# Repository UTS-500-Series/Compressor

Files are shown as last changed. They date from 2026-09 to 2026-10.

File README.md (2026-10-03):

# UTS Mini Mixing Desk — Compressor

A 500-series compressor module for the UTS Mini Mixing Desk. Feedback topology, discrete
current-steering gain cell, balanced in and out, running on the rack's ±16 V.

Built from ordinary parts: **nine BC549 transistors and seven NE5532 op amps**, plus a
pair of LM391x bargraph drivers for the meters. No VCA chip,
no transformers, nothing hard to source.

📖 **Documentation: [uts-500-series.github.io/compressor](https://uts-500-series.github.io/compressor/)** — every section explained, with
interactive schematics you can click through, plus the routed boards and their design files.
The site's source is a separate repository, [UTS-500-Series.github.io](https://github.com/UTS-500-Series/UTS-500-Series.github.io).

---

## Status

| | |
|---|---|
| Schematic | Complete, 7 sheets |
| Components | 166 |
| Nets | 110 |
| ERC | 0 errors, 0 warnings |
| PCB layout | Main board and front board placed and routed, DRC clean. Main board re-routed with paired audio lines and an unbroken ground pour; front board still as autorouted |
| Simulated | Yes, in ngspice from the `kicad/` sheets. See [kicad/sim](kicad/sim/README.md) |
| Built | No |

**Every performance figure in the documentation is calculated from the design, not measured.**
The netlist has been verified and ERC is clean, but that only proves the drawing is
self-consistent — not that the circuit behaves as predicted. The [simulation](kicad/sim/README.md)
checks the behaviour with models of the real parts, and found a few places where it differs
from the documentation.

## Repository layout

```
kicad_withpcb/compressor_with_pcb/   the main board: flat schematic + routed PCB (KiCad 10)
kicad_withpcb/compressor_front/      the front board behind the panel: schematic + routed PCB
kicad/                               the original seven-sheet schematic (KiCad 9), used by the site
tools/                               design.py (the reference netlist) and the check/build scripts
panel/                               faceplate generator — mockups, a 1:1 drawing and a DXF
```

**The boards are built from `kicad_withpcb/`.** The flat schematic there drives the main
board's PCB, and the front board has its own schematic joined to it by a 30-way ribbon.
`tools/design.py` is the reference netlist. Compare the flat schematic against it after any
wiring edit: KiCad's DRC parity check only compares the PCB with the flat schematic, so it
can't see a wiring mistake in the schematic itself.

The seven-sheet `kicad/` project is the original drawing of the same circuit. It has no PCB,
but the documentation site's interactive schematics are built from it. The site lives in its
own repository, [UTS-500-Series.github.io](https://github.com/UTS-500-Series/UTS-500-Series.github.io),
because it covers the whole desk rather than this module.

## Opening it

The boards need **KiCad 10**:

- `kicad_withpcb/compressor_with_pcb/compressor_with_pcb.kicad_pro`: the main board, the
  500-series card (152.35 × 105 mm) with the edge connector.
- `kicad_withpcb/compressor_front/compressor_front.kicad_pro`: the 35 × 110 mm front board
  with the pots, toggles and meters. Its [README](kicad_withpcb/compressor_front/README.md)
  covers how it mounts, the ribbon, the bracket and what to check before ordering.

Run `sh tools/get_3d_models.sh` once after cloning. It fetches Alps' RK09K pot model, which
isn't kept in git, so the 3D viewer and STEP export show the pots.

The original schematic is `kicad/UTS Mini Mixing Desk - Compressor.kicad_pro` (**KiCad 9**). Its root sheet holds seven
sub-sheets:

| Sheet | What it covers |
|---|---|
| 1 Connector | The 500-series edge connector |
| 2 Input | Balanced receiver and the input pad |
| 3 VCA | The current-steering gain cell and recovery amplifier |
| 4 Output | Makeup gain, output drivers, bypass, aux section |
| 5 Sidechain | Detector: threshold, rectifier, ratio, attack/release |
| 6 Power | Rails, references, bias, grounding, decoupling |
| 7 Meters | Gain-reduction and output-level LED bargraphs |

Only stock KiCad symbol and footprint libraries are used, so there is nothing to install.

## How it works, in one paragraph

A compressor needs a gain it can change electrically, and a way to measure loudness. The gain
cell here keeps a **fixed 3 mA tail current** through a matched BC549 pair and varies gain by
*steering* that current between an output load and the supply rail, rather than by varying the
current itself. That costs four extra transistors and buys a distortion figure that stays flat
at every amount of gain reduction — the simpler tail-current approach distorts worst exactly
when it is compressing hardest. The detector listens to the module's own **output**, making
this a feedback compressor: the ratio emerges from loop gain rather than being dialled in, the
knee comes out soft on its own, and the circuit is forgiving of component tolerance.

The [documentation](../UTS-500-Series.github.io) covers all of this properly, section by section.

## Specifications

| | |
|---|---|
| Format | 500 series, 15-pin EDAC card edge |
| Supply | ±16 V from the rack, 72 / 62 mA at rest (simulated) |
| Input | Balanced, 44 kΩ differential, +4 dBu nominal |
| Output | Balanced, 100 Ω build-out per leg |
| Gain reduction | 36 dB maximum (simulated) |
| Attack | 2 – 71 ms (simulated) |
| Release | 49 ms – 3.5 s (simulated) |
| Controls | Threshold, Ratio, Attack, Release, Makeup |
| Switches | Bypass, sidechain key int/ext, sidechain HPF, stereo link |

## Front panel

[`panel/`](panel/) holds the faceplate: a mockup, a dimensioned 1:1 drawing, and a DXF of the
outline and holes for a panel shop. All three are generated from one definition by
`panel/make_panel.py`, which runs a clearance check on every build.

Panel is the standard 500-series 1.500″ × 5.250″ × 0.125″ with two countersunk mounting holes
125.43 mm apart, badged **OPN-500 / CMP-01**.

The default layout, and the one the front board is built for, is **`toggle`**: five single
9 mm pots (THRESHOLD, RATIO, ATTACK, RELEASE, MAKEUP), four mini toggles (HPF and KEY
either side of THRESHOLD, LINK and BYPASS either side of RATIO), and two 10-LED meters for
gain reduction and output level. That's 31 holes, and `make_panel.py` takes their
positions from the front board. The toggles are Salecom mini toggles from Altronics:
S1350 (DPDT) for BYPASS and S1315 (SPDT) for KEY, HPF and LINK, in 6.5 mm holes for their
1/4-40 bushings. The S1332 (SPDT centre-off) fits the same footprint if a three-position
switch is ever wanted.

The toggles' 8.9 mm bushing leaves about 5.5 mm of thread through a 3.18 mm panel, so they
are no longer the tight spot. The 9 mm pots are: their 5 mm bushing leaves under 2 mm for
the nut, so thin the panel to about 2 mm around the five pot holes, or use a thinner panel.

`make_panel.py` also keeps a `pull` layout (every switch on a pull-switch pot) and a
`concentric` layout (dual-concentric knobs and a lit BYPASS button), plus a `bone` finish
alongside the default dark anodised one. The boards are only drawn for `toggle`. See
[`panel/README.md`](panel/README.md).

No laser cutter or CNC? [`panel/print/`](panel/print/README.md) has a 3D-printable faceplate
(STL and OpenSCAD) with the same holes, pot wells for the short pot bushings, an engraved
legend that can print in a second colour, and a fit-test strip to print first.

## Bill of materials

**[`bom/altronics.csv`](bom/altronics.csv)** is the order list for both boards from Altronics,
with catalogue codes, pack sizes, prices and the stock their site showed on the day it was
checked. `python3 tools/bom_altronics.py` rebuilds it from the two `kicad_withpcb`
schematics, so it follows the boards rather than `design.py`; a part drawn on both sheets
is counted once, on the front board. It includes the hardware the schematics don't: DIP-8
sockets for U1–U7, knobs, the board-to-board ribbon and M3 screws for the bracket. The
two LM3914 meter drivers are soldered straight in, because sockets would overlap the
meter LEDs.

Altronics doesn't stock everything. The script lists those lines with another supplier:
the 2.2–10 µF film capacitors, R61/R62 at 0.1%, and the twenty 2 mm meter LEDs (Altronics'
3 mm flangeless LEDs don't fit the meters' 3.0 mm pitch). The film capacitors come from element14, and
the main board is drawn for those exact parts: TDK B32562H1106K000 (10 µF, C5, C8, C15) and
B32562H1475K000 (4.7 µF, C9, C10), both 15 mm pitch, and KEMET MMK5225K63J06L4BULK
(2.2 µF, C14, C35) on 5 mm. RV5 (ATTACK) is 10k and RV6 (RELEASE) 1M, Altronics' nearest
9 mm values.

The output-level meter was an LM3915, whose ten steps are 3 dB apart. Nobody stocks it any
more, so U10 is now an LM3914 like the gain-reduction meter, and both meters have ten LEDs on
a 3.0 mm pitch (they had seven on 3.5 mm). R92 is 4k7, so RV8 can set the top level LED at
+18 dBu. The LM3914's steps are even in volts, so the level LEDs light at about −2, +4, +7.5,
+10, +12, +13.6, +15, +16, +17 and +18 dBu: a 20 dB span with the finest steps near
clipping. With RV7 set for a 30 dB top LED, the gain-reduction LEDs light at about 2, 3, 5,
7, 10, 13, 17, 21, 26 and 30 dB. Both scales are simulated: see
[kicad/sim/README.md](kicad/sim/README.md#the-meters).
`tools/bom_order.py` is the older DigiKey list, built from `design.py`.

The circuit itself is 172 components across 58 distinct line items: 73 resistors, 39 capacitors, 21 LEDs,
9 transistors, 8 potentiometers, 8 diodes, 7 op amps, 4 switches, 2 display drivers,
1 connector.

Four things are not substitutable:

- **Q1/Q2 must be a matched pair, and Q6–Q9 a matched quad**, all glued together so they stay
  at the same temperature. The steering balance is set by base-emitter voltages differing by
  tens of millivolts, and those drift ~2 mV per °C.
- **R1–R4 and R21–R24 want 0.1%.** R1–R4 set input common-mode rejection; R21–R24 set how well
  the recovery amp rejects the gain cell's step, which is audible as thump on fast attacks.
- **R61 (1k33) and R62 (23k2) want 0.1%.** They set the gain cell's resting point.
- **C15 must be film.** An electrolytic's leakage is in the same league as the release current
  at long settings and will shorten your slowest release.

One recommended deviation: fit a **TL072 or OPA2134 for U4** instead of an NE5532. Its inputs
sit on the timing capacitor, and the NE5532's ~200 nA bias current can leave the compressor
holding about a decibel of gain reduction at idle. Pin compatible, nothing else changes.

## Ordering the boards

Each board's fab files are in its `Gerbs/` folder, zipped ready to upload:
`kicad_withpcb/compressor_with_pcb/Gerbs/compressor_with_pcb-gerbers.zip` (main board,
128.4 × 105.05 mm including the edge-connector tab) and
`kicad_withpcb/compressor_front/Gerbs/compressor_front-gerbers.zip` (front board, 35 × 110 mm).
Both are 2-layer, 1.6 mm FR-4, 1 oz copper, through-hole only (no paste layers). Smallest
track 0.2 mm, clearance 0.2 mm, drill 0.4 mm, so any standard fab process takes them.

The main board's edge fingers plug into the rack, so ask for gold fingers with a 30–45° bevel
if the fab offers it. Plain HASL works for a prototype but wears with repeated insertion.

**Re-plot after every board change**, so the zips never lag the board:

```bash
sh tools/plot_fab.sh                 # both boards, needs KiCad 10's kicad-cli
```

## Documentation site

The site is a **separate repository**, checked out beside this one as `../UTS-500-Series.github.io`. It covers
every module in the desk — compressor, preamp and equaliser — so it does not belong to any
one of them. It also owns its own GitHub Pages workflow.

The compressor's pages are interactive: pan and zoom the real schematic, click any part for
its value, footprint and nets, click a net to highlight everything on it, or switch to a
graph view of the netlist.

The site commits its generated data, so it builds and publishes without this repository
present. It only needs this one checked out when the schematic changes — see below.

## Tooling

Everything needed to check and rebuild the project lives in [`tools/`](tools/) — standard
library only, no packages to install. KiCad's paths are found automatically; override with
`KICAD_CLI` and `KICAD_SYMBOL_DIR` if yours are somewhere unusual.

```bash
python3 tools/verify_netlist.py      # check the schematic against design.py
sh tools/plot_fab.sh                 # plot Gerbers + drill files for both boards
```

`tools/gen_project.py` and `tools/route_sch.py` **regenerate the schematic from scratch and
will overwrite hand-drawn layout.** They built the first version; the sheets have been laid out
by hand since. See [`tools/README.md`](tools/README.md) before running either.

## How the schematic is verified

`tools/design.py` holds the netlist as data and is treated as the source of truth.
`tools/verify_netlist.py` exports the netlist from the schematic with `kicad-cli` and diffs it
against that definition **net by net and pin by pin**.

That is what catches the failure mode ERC cannot see: a wire dragged so its endpoint lands on a
neighbouring node shorts two signal nets together, and ERC reports nothing, because every pin
is still connected to *something*. Two such shorts were caught and fixed this way during layout
cleanup. Worth running after any significant edit — it takes a second and prints the exact nets
and pins involved when something is wrong.

## Regenerating the documentation

After changing a sheet, from the **docs** repository beside this one:

```bash
# 1. re-export the sheet images
kicad-cli sch export svg --no-background-color --exclude-drawing-sheet -o /tmp/svg \
  "kicad/UTS Mini Mixing Desk - Compressor.kicad_sch"
#    copy the seven sheets into ../UTS-500-Series.github.io/site/compressor/img/ as connector.svg, input.svg,
#    vca.svg, output.svg, sidechain.svg, power.svg, meters.svg

cd ../UTS-500-Series.github.io
python3 build/_data.py --module compressor   # hotspots + netlist graph, read from kicad/
python3 build/build_site.py                  # every page, every module
```

Both scripts import from `tools/`, so a fresh clone has everything it needs.

## Known gaps

- **The main board was re-routed by script, not by hand, so look it over in KiCad before
  ordering.** IN± and OUT± now run as pairs 0.6 mm apart on the top layer, with one via each
  on IN− and OUT− beside the edge fingers. Nearly everything else moved to the top so the AGND
  pour on the bottom is one piece (it was seven, one of them cut off near the fingers). The cost
  is more vias: 155, up from 37. The timing node (C15, U4, D7, J2) is 44 mm, about as short as
  the placement allows; shortening it further means moving C15.
- **The front board's tracks are still as the autorouter left them**, with its ground pour in
  12 pieces. It carries the bypass switch's IN± and OUT± runs, so tidy those if anything.
- **Check one toggle and one pot against their footprints before ordering boards.** The
  Salecom footprints follow the drawings on Altronics' product pages; Altronics doesn't
  dimension where the 9 mm pot's shaft sits relative to its lugs, so confirm it lines up
  with the panel hole.
- **Check the mechanics in a real rack:** the front board now sits about 10.6 mm behind the
  panel (the pots' body height; the toggles stand 10.4 mm), the panel thickness at the pots,
  the ribbon length (about 150 mm is an estimate), and that the ribbon plug on J1 still
  clears the main board's front edge, 24 mm back.
- **The main board was re-placed and re-routed by script to fit the full-size film
  capacitors.** The film caps went in near their old spots, 56 resistors, small caps and
  diodes moved or swapped places to make room (transistors, ICs, connectors and trimmers
  stayed put), and the whole board was re-routed by script (see the item above). Keep the
  timing node (C15, U4) and the recovery-amp inputs (C9, C10, R21, R22, U1) short if you
  move anything.
- Pin 11 is used as an auxiliary input, which the API 500 specification assigns to a gain-trim
  node. The aux section (U5 and its resistors) is a separable block; omit it and the module is
  fully standards-compliant.
- Simulated in ngspice only (see [kicad/sim](kicad/sim/README.md)): no instability at the
  fastest attack and hardest ratio there, but the op amp model is behavioural, so check on the bench.

## Licence

Copyright 2026 the UTS 500 Series team.

This source describes Open Hardware and is licensed under the CERN-OHL-S v2.

You may redistribute and modify this source and make products using it under
the terms of the [CERN-OHL-S v2](https://ohwr.org/cern_ohl_s_v2.txt).

This source is distributed WITHOUT ANY EXPRESS OR IMPLIED WARRANTY, INCLUDING
OF MERCHANTABILITY, SATISFACTORY QUALITY AND FITNESS FOR A PARTICULAR PURPOSE.
Please see the CERN-OHL-S v2 for applicable conditions.

Source location: https://github.com/UTS-500-Series/Compressor

As per CERN-OHL-S v2 section 4, should You produce hardware based on this
source, You must where practicable maintain the Source Location visible on the
external case of the compressor module or other products you make
using this source.

The full licence text is in [LICENSE](LICENSE).

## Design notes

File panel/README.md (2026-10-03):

# Front panel — OPN-500 / CMP-01

Faceplate mockup and machining data for the compressor module.

Faceplate

| File | What it is |
|---|---|
| `faceplate-mockup.svg` | How it looks — whichever finish you built last. |
| `faceplate-mockup-bone.svg` | The other finish, written every run so you can compare. |
| `faceplate-drawing.svg` | 1:1 technical drawing, dimensioned, for checking before you cut. |
| `faceplate.dxf` | Outline and holes only, for a panel shop or CNC. |
| `make_panel.py` | Generates all of it from one definition. |
| [`print/`](print/README.md) | A 3D-printable version: STLs, the OpenSCAD model and print settings. |

Everything comes out of `make_panel.py`, so the picture and the machining data cannot drift
apart. Change a control position once and re-run:

```bash
python3 make_panel.py                          # toggle layout, anodised (default)
python3 make_panel.py --layout pull            # five knobs, every switch a pull
python3 make_panel.py --layout concentric      # concentric knobs, button, toggles
python3 make_panel.py --style bone             # light flat-graphic finish
python3 make_panel.py --layout toggle --style bone
```

## Layouts

The layout changes **what hardware is on the panel**, so the hole pattern, the drawing and the
DXF all change with it.

**`pull`** — five separate knobs. Every switch function is a pull on a pot, so
there are no toggles and no button at all: THRESHOLD pulls for the sidechain HPF, RATIO for
key int/ext, MAKEUP for bypass. LINK is an internal jumper. **27 holes.** The simplest panel
to build and the cheapest to populate, at the cost of a slow, uncertain bypass action.

*A note on the shared row:* ATTACK and RELEASE sit side by side on every layout, so they get a
smaller legend and no printed numerals — two full scales would print their endpoints on top of
each other in the gap between the knobs.

**`toggle`** *(default, and the one the front board is built for)* — the same five knobs, but every switch gets its own toggle rather than hiding on
a pull. They flank the two knobs they belong to: HPF and KEY either side of THRESHOLD, LINK and
BYPASS either side of RATIO. **31 holes.** Four more holes and four more parts than `pull`, and
in exchange every function is one positive movement — nothing is hidden, and bypass is instant.
The most parts of the three layouts, and the easiest to use.

**`concentric`** — two dual-concentric knobs (THRESHOLD/RATIO, ATTACK/RELEASE) free the space
for a latching illuminated BYPASS button and HPF / KEY toggles; LINK moves to the pull on
MAKEUP. **28 holes.** Better ergonomics, but concentric pots are dearer, harder to source, and
their inner shafts cannot carry a printed scale.

## Finishes

**`anodised`** *(default)* — dark panel, knurled knobs, teal accents. Reads as studio hardware.
The recessed meter window and the DYNAMICS / OUTPUT section rules appear on the concentric
layout only; the pull layout is plainer because it has no room for them.

**`bone`** — light panel, flat graphic treatment, printed dot scales with 0–10 numerals, thin
metal bat toggles, sage and terracotta. Closer to a plugin UI than a rack unit.

Every run writes the chosen combination as `faceplate-mockup.svg` and the other finish as
`faceplate-mockup-<name>.svg`, so comparing costs nothing.

## Panel dimensions

From the API 500 mechanical specification, not guessed:

| | Imperial | Metric |
|---|---|---|
| Width | 1.500″ | 38.10 mm |
| Height | 5.250″ | 133.35 mm |
| Thickness | 0.125″ | 3.18 mm |
| Mounting hole pitch | 4.938″ | 125.43 mm |
| Mounting hole Ø | 0.125″ | 3.18 mm |
| Countersink | 82° to 0.225″ | 82° to 5.72 mm |

Both mounting holes sit on the vertical centreline at x = 19.05 mm, which puts them
3.96 mm from each end.

## Drill schedule

For the `toggle` layout, which is what the front board (`kicad_withpcb/compressor_front`)
carries. That board is the master: these positions are copied from it, so change the board
first and then the numbers in `make_panel.py`.

Origin is the **top-left corner** of the panel, x right, y down. All in millimetres.

| Ref | Function | X (mm) | Y (mm) | Hole Ø | Hardware |
|---|---|---|---|---|---|
| `RV3` | THRESHOLD | 19.05 | 52.00 | 7.2 | 9 mm pot (Altronics R19xx or Alps RK09K), M7 bushing |
| `RV4` | RATIO | 19.05 | 72.50 | 7.2 | 9 mm pot |
| `RV5` | ATTACK | 10.00 | 91.00 | 7.2 | 9 mm pot |
| `RV6` | RELEASE | 25.10 | 91.00 | 7.2 | 9 mm pot |
| `RV2` | MAKEUP | 19.05 | 111.00 | 7.2 | 9 mm pot |
| `SW3` | HPF | 7.15 | 52.00 | 6.5 | mini toggle, SPDT, 1/4-40 bushing (Salecom S1315) |
| `SW2` | KEY | 30.95 | 52.00 | 6.5 | mini toggle, SPDT (Salecom S1315) |
| `SW4` | LINK | 7.15 | 72.50 | 6.5 | mini toggle, SPDT (Salecom S1315) |
| `SW1` | BYPASS | 30.95 | 72.50 | 6.5 | mini toggle, DPDT (Salecom S1350) |
| `D20`–`D29` | GR meter, 10 seg (D20 at the top) | 14.10 | 14.0 to 41.0, 3.0 pitch | 2.2 | 2 mm flat-top LED |
| `D30`–`D39` | LVL meter, 10 seg (D39 at the top) | 24.00 | 14.0 to 41.0, 3.0 pitch | 2.2 | 2 mm flat-top LED |
| — | mounting | 19.05 | 3.96 | 3.18 | c'sink 82° to Ø5.72 |
| — | mounting | 19.05 | 129.39 | 3.18 | c'sink 82° to Ø5.72 |

The front board sits about 10.6 mm behind the panel, set by the 9 mm pots' body height
(the toggles stand 10.4 mm). The toggles' 8.9 mm bushing leaves about 5.5 mm of thread in
front of a 3.18 mm panel, plenty for the washer and nut. The pots' 5 mm bushing leaves
under 2 mm, so thin the panel to about 2 mm around the five pot holes (a counterbore from
the back), or use a 1.6 to 2 mm panel. The toggles come with a tabbed locking washer; drill
a small hole for its tab if you want it, or flatten the tab.

The toggles sit 0.25 mm in from where the old sub-miniature ones were, so the S1350's
11.4 mm body stays on the 35 mm front board. In the `toggle` layout `make_panel.py` also
checks the switch and pot bodies behind the panel: each stays on the front board and at
least 0.5 mm from its neighbours. The tightest pair is BYPASS and RATIO, 1.3 mm apart.

ATTACK and RELEASE sit 1.5 mm left of symmetric so the ribbon header on the back of the
front board clears the RELEASE pot. The meter columns are 9.9 mm apart rather than 10.9 so
the two LM3914 meter drivers fit either side of them.

## Layout notes

**Dual-concentric knobs carry the four paired controls.** THRESHOLD over RATIO, ATTACK over
RELEASE — the outer ring is dark and knurled, the inner cap amber, so which one you have hold
of is obvious. This is what buys the room for two meters, a button and two toggles on a
38 mm panel; four separate knobs would eat 40 mm of height on their own.

The trade is cost and sourcing: dual-concentric pots are dearer and harder to find than two
singles, and you generally **cannot get a pull switch on one**, which is why the switch
functions live elsewhere.

**Control map**

| Position | Outer / primary | Inner / secondary |
|---|---|---|
| Upper concentric | THRESHOLD | RATIO |
| Lower concentric | ATTACK | RELEASE |
| Single knob | MAKEUP | pull for LINK |
| Button | BYPASS (latching, lit) | — |
| Toggles | HPF, KEY | — |

**`BYPASS` is a latching pushbutton** legended on its own face. The bottom screw owns the
centreline down there and there is no room for a legend beside it; putting the word on the cap
is what a real panel does anyway. It is illuminated, so bypass state is visible across a room.

**`LINK` is a pull on MAKEUP.** It is set once per stereo pair and then left, which makes it
the right function to hide behind a pull rather than give a switch to.

**Two 10-segment meters.** `GR` fills downward from the top as the compressor clamps; `LVL`
fills upward, green through amber to red. Twenty 2 mm LEDs on a 3.0 mm pitch, in a recessed
window, driven by two LM3914s in dot mode (one LED lit at a time; the mockups show a bar to
make the scale readable). The 3.0 mm pitch leaves 0.8 mm of metal between the 2.2 mm holes,
which `make_panel.py` allows for the meter holes only; everything else keeps 1.0 mm.

**On keeping every round.** The panel went through several iterations and only the most recent
reached git, so two earlier versions had to be rebuilt from scratch to get them back. Hence
`--layout` and `--style`: four combinations now regenerate from one definition and none can be
lost by choosing another. Commit after a round you like.

## Before you have it made

- **Hardware is assumed, not specified.** Hole sizes suit a 9 mm pot bushing, a mini toggle
  and a 3 mm LED bezel. Check them against the parts you actually buy — bushing diameters
  vary between manufacturers and a 0.5 mm error is the difference between a push fit and a
  rattle.
- **Depth is not modelled.** The body footprints behind the panel are checked (toggle layout),
  but heights are not. Confirm that knobs, switch bodies and the LEDs clear the PCB and the
  neighbouring module before committing.
- **The countersink is on the front face**, so the screw sits flush with the panel.
- Silkscreen colours in the mockup are indicative. Ask your finisher what they can hold.

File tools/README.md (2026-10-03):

# Tools

Python helpers for this project. No dependencies beyond the standard library — they call
`kicad-cli` for anything that needs KiCad itself.

Both KiCad paths are discovered automatically, with environment overrides if yours are
somewhere unusual:

```bash
export KICAD_CLI=/path/to/kicad-cli
export KICAD_SYMBOL_DIR=/path/to/kicad/symbols
```

## Safe to run any time

| Script | What it does |
|---|---|
| `verify_netlist.py` | Exports the netlist with `kicad-cli` and diffs it against `design.py`, net by net and pin by pin. **Run this after any significant edit.** |
| `sexp.py` | KiCad s-expression parser and symbol-library resolver. Imported by the others. |
| `design.py` | The netlist as data — the source of truth everything is checked against. |
| `bom_altronics.py` | Writes `bom/altronics.csv`, the Altronics order list for both boards, from the `kicad_withpcb` schematics. Prices and stock are what the site showed on the date in the script. |
| `bom_order.py` | The older DigiKey order list, from `design.py`. |
| `make_toggle_models.py` | Writes the STEP models for the Salecom toggles on the front board. |
| `plot_fab.sh` | Plots Gerbers and drill files for both boards into each board's `Gerbs/` folder and zips them for the fab. Set `KICAD_CLI` if `kicad-cli` isn't on your PATH (on a Mac it's inside KiCad.app). |

```bash
python3 tools/verify_netlist.py
```

## Destructive — read before running

> ⚠️ **`gen_project.py` and `route_sch.py` regenerate the schematic from scratch and will
> overwrite every sheet, destroying hand-drawn layout.** They built the first version of this
> project; the sheets have been laid out by hand since. Do not run them unless you actually
> want to start the drawing again.

| Script | What it does |
|---|---|
| `gen_project.py` | Regenerates the whole seven-sheet project: placement, routing, verification. |
| `route_sch.py` | Single-sheet router, plus the symbol geometry helpers the other tools import. |
| `place.py` | Placement rules — anchors, slots, and the power-sheet grouping. |

If you do want to regenerate, commit first, and write to a scratch directory:

```bash
python3 tools/gen_project.py -d /tmp/regenerated
```

## Editing the design

`design.py` is the authoritative netlist. Change a value there **and** in the schematic, then
run `verify_netlist.py` to confirm the two still agree. If they disagree, the tool prints the
exact nets and pins involved.

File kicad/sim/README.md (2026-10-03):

# Simulating the compressor

The seven-sheet schematic in `kicad/` simulates in KiCad's own simulator (ngspice). Every part
has a SPICE model, and the root sheet carries a small test bench: the rack's ±16 V, a balanced
1 kHz source, a 20 k balanced load, and one line of knob settings.

## Running it in KiCad

1. Open `kicad/UTS Mini Mixing Desk - Compressor.kicad_pro` in KiCad 10 (the sheets are saved in its format).
2. **Inspect → Simulator**, then **New Analysis Tab** and pick **Transient**. Something like
   step `10u`, stop `0.6` and max step `20u` works (in a `.tran` line: `.tran 10u 0.6 0 20u`).
   For the frequency response, pick **AC** instead, decade sweep from 10 Hz to 100 kHz.
3. Run it, then probe nets in the schematic. The useful ones:

| Net | What it shows |
|---|---|
| `OUT_DIFF` | The balanced output, OUT+ minus OUT- (a test-bench probe) |
| `OUT-A` | The makeup amp's output, the hot leg before the build-out resistor |
| `CTRL-B` | The control voltage: 0 V at rest, going negative as it compresses |
| `STB`, `STA` | The steering pair. STB minus STA is what sets the gain |
| `TIMING` | The attack/release capacitor C15 |
| `SIG-VCA` | After the gain cell and recovery amp |

The AC source is 1 V differential, so an AC run reads gain directly.

## Changing the settings

The knobs are `.param` lines in the text block at the bottom of the root sheet. Edit the text
and run again.

| Param | Part | 0 means | 1 means |
|---|---|---|---|
| `LEVEL_DBU` | source | input level in dBu, differential | |
| `FREQ` | source | tone frequency in Hz | |
| `THRESHOLD` | RV3 | 0 Ω: lowest threshold, about −20 dBu | 100 kΩ (audio taper): about +20 dBu |
| `RATIO` | RV4 | wiper at the rectifier: hardest | wiper at ground: no compression |
| `ATTACK` | RV5 | 0 Ω: fastest | 10 k: slowest |
| `RELEASE` | RV6 | 0 Ω: fastest | 1 M: slowest |
| `MAKEUP` | RV2 | 0 dB | +21 dB |
| `TRIM` | RV1 | unity trim | |
| `GRTRIM`, `LVLTRIM` | RV7, RV8 | meter trims | |
| `BYPASS`, `KEY` | SW1, SW2 | in, internal key | bypassed, external key |
| `HPF_DEFEAT`, `LINK` | SW3, SW4 | sidechain HPF in, link open | HPF shorted out, link closed |

Pot positions are where the wiper sits between pin 1 (0) and pin 3 (1), so they are not
necessarily the knob's clockwise direction. RATIO is the exception: RV4 is wired with its
outer pins swapped, so its model reads `POS={1-RATIO}` and `RATIO` keeps the meaning in the
table. See the note on pot direction in the results.

## The models

All in `compressor_models.lib`, which says where each one comes from:

- **BC549C**: Philips' model.
- **1N4148, 1N4004**: vendor models. **BZX79C5V1** and the **LEDs**: generic models.
- **NE5532**: a behavioural model written for this design. TI's 1989 macromodel was tried
  first, but ngspice aborts on its output current limiter when the meter's peak detector
  swings. The behavioural one has the real part's gain, bandwidth, slew rate, input bias,
  swing and current limit, but no noise and no distortion of its own until it clips.
- **LM3914N** (both meter drivers): a behavioural model written for this design. It has the
  1.25 V reference, the ten-step divider, ten comparators, dot or bar mode from pin 9, and LED
  outputs that sink 10 times the current drawn from REFOUT. That current includes the
  internal divider's, which may read a little high against a real part. No hysteresis or
  comparator offsets.
- **Pots and switches**: ideal, set by the parameters above. A pot whose value ends in A
  (RV3, 100kA) has an audio taper: 10% of its resistance at half travel.

`tools/add_sim_models.py` writes the `Sim.*` fields onto the sheets. Run it again if the
sheets are regenerated, or if you add a part that needs a model. The `.options rshunt=1e9`
line on the bench matters: without it ngspice stalls once the compressor is working hard.

## Running it without the KiCad GUI

`tools/sim/` has the scripts that produced the results below. They export the netlist with
`kicad-cli sch export netlist --format spice` and run ngspice in batch mode:

```
python3 tools/sim/run_all.py      # needs kicad-cli, ngspice, numpy, matplotlib
python3 tools/sim/meters.py       # the two LED meters, about 10 minutes
```

## Results

Run on 2 October 2026 with kicad-cli 10.0.6 and ngspice 42, from the sheets as they are on this
branch. Levels are balanced (differential) dBu, at 1 kHz, makeup at 0, attack and release at
half travel unless it says otherwise. `results/results.json` has every number.

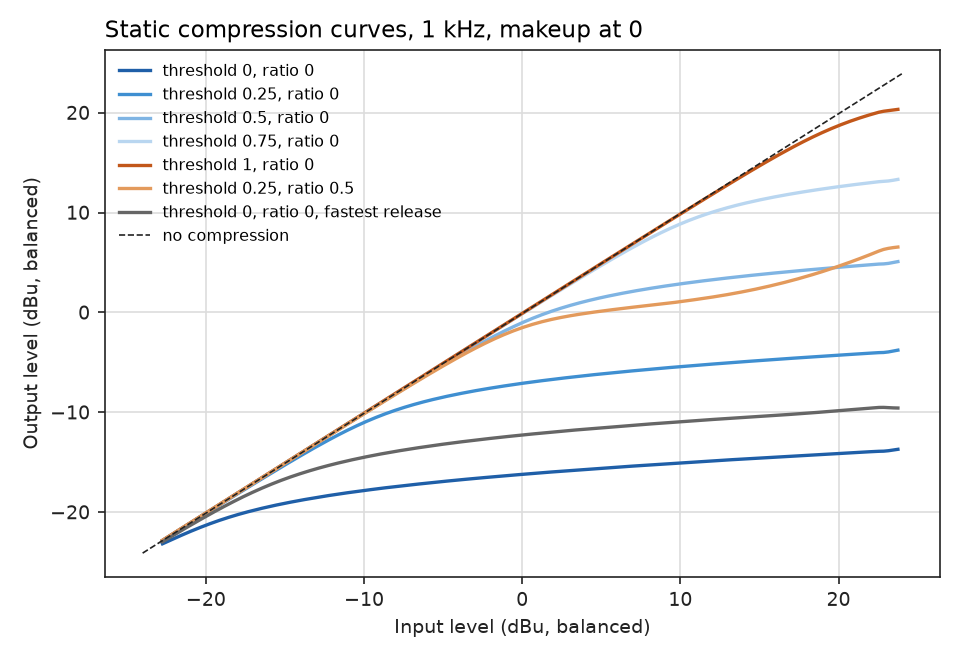
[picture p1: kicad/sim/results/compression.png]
Compression curves


**It works as a compressor, and now meets most of its design targets.** The first simulation
(1 October, values as they were on `main`) found the module had 6 dB of gain, an early bass
roll-off, a threshold that did all its work in the first quarter of RV3, and attack and release
much faster than the RC values suggest. Fourteen part values changed to fix that; no connections
moved, so the board layouts keep their routing.

| Part | Was | Now | Why |
|---|---|---|---|
| R21, R22 | 3k3 | 6k8 | Halves the recovery amp's gain: the module is unity and BYPASS matches |
| C9, C10 | 2u2 | 4u7 | With the larger R21/R22, the bass corner drops from 22 Hz to about 5 Hz |
| R36 | 100k | 82k | With R35 and RV3, sets the detector gain range |
| RV3 | 1M linear | 100kA | Spreads the threshold evenly over the knob; RK09K stops at 100k |
| R35 | 20k | 1k | Sets the lowest threshold at −20 dBu |
| R38, C14 | 10k, 220n | 1k, 2u2 | Holds the sidechain high-pass between 80 and 160 Hz over the threshold knob; with R38 at 10k the small R35 pushed it to 400 Hz at low thresholds |
| R60 | 47k | 24k | Restores the 150 mV resting steer (VREF5 now 5.77 V, close to the 5.49 V on the power page) |
| C22 | 47u | 4u7 | Stops the steering overshooting by up to 20 dB on a fast attack (below) |
| R47 | 4k7 | 15k | Fastest release near 47 ms; the release pot loads the detector less |
| RV5 | 4k7 | 10k | Altronics' 9 mm pots come in 10k, 100k and 1M only |
| RV6 | 220k | 1M | Same; slows the slowest release past the 2.2 s target |

| | Before | Now | Target |
|---|---|---|---|
| Gain at 1 kHz, balanced in to out | +5.8 dB | −0.1 dB | 0 dB |
| RV1 trim range | +4.9 to +6.8 dB | +0.9 to −1.0 dB | covers 0 dB |
| −3 dB points | 22 Hz, 60 kHz | 5.6 Hz, 60 kHz | 20 Hz to 20 kHz |
| Threshold (1 dB of reduction) | −9 to above +20 dBu | −21 to +19 dBu | −20 to +14 dBu |
| Threshold at RV3 0, ¼, ½, ¾, 1 | −9, +14, above +20 by ½ | −21, −10, 0, +10, +19 | an even spread |
| Most reduction (+22 dBu in) | 22 dB | 36 dB | about 40 dB |
| Attack, fastest to slowest | 1 to 14 ms | 2 to 71 ms | 2.7 to 50 ms |
| Release, fastest to slowest | 20 ms to 0.44 s | 49 ms to 3.5 s | 47 ms to 2.2 s |
| Resting steer, VREF5 | 94 mV, 3.60 V | 150 mV, 5.75 V | 150 mV, 5.49 V |
| CTRL-B at most reduction | −4.5 V | −8.0 V | −10 V |
| Supply at rest, +16 / −16 V | 72 / 61 mA | 72 / 62 mA | about 60 mA |

Distortion stays low while it compresses, which is the whole point of the steering cell:

| Condition | Out | Gain reduction | THD |
|---|---|---|---|
| +4 dBu in, not compressing | +3.9 dBu | 0 | 0.008% |
| +4 dBu in, makeup at full | +24.7 dBu | 0 | 0.010% |
| +8 dBu in, threshold at ¼ | −5.9 dBu | 13.8 dB | 0.013% |
| +8 dBu in, threshold lowest | −15.5 dBu | 23.3 dB | 0.026% |
| +16 dBu in, threshold lowest | −14.7 dBu | 30.5 dB | 0.031% |
| +16 / +20 / +22 dBu in, not compressing | | 0 | 0.033% / 0.057% / 0.079% |
| +24 dBu in, not compressing | | 0 | 6.2%, the input stage clipping |

The op amp model has no distortion of its own below clipping, so these figures are the gain
cell's. Real NE5532s add a little.

### The meters

Run on 3 October 2026 by `tools/sim/meters.py`, with the LM3914 model above and ten LEDs per
meter. `results/meters.json` has the numbers.

- **Level (U10).** RV8 set so the top LED lights at +18 dBu out: that needs RV8 at 0.22 of its
  travel (R92 is 4k7, so the reference is 3.43 V). Steps are even in volts, so they close up
  towards the top.
- **Gain reduction (U9).** RV7 at 0.556 puts the top LED at about 30 dB. The R93 offset and
  the gain cell's curve spread the steps out from 2 dB to 30 dB.
- **Each lit LED draws 9.6 mA** on the level meter. The GR meter's reference also feeds R93,
  so by the same rule its LEDs run a little brighter, about 12 mA.

| LED | Level meter | lights at | GR meter | lights at |
|---|---|---|---|---|
| 1 | D30 | -1.8 dBu | D20 | 1.8 dB |
| 2 | D31 | +4.1 dBu | D21 | 3.1 dB |
| 3 | D32 | +7.5 dBu | D22 | 4.7 dB |
| 4 | D33 | +10.1 dBu | D23 | 6.8 dB |
| 5 | D34 | +12.0 dBu | D24 | 9.6 dB |
| 6 | D35 | +13.6 dBu | D25 | 12.9 dB |
| 7 | D36 | +14.8 dBu | D26 | 16.7 dB |
| 8 | D37 | +16.0 dBu | D27 | 21.1 dB |
| 9 | D38 | +17.1 dBu | D28 | 25.7 dB |
| 10 | D39 | +18.0 dBu | D29 | 30.4 dB |

On a +20 dBu burst with the threshold at half travel, the level meter hits its top LED for
the first 15 ms or so, until the attack catches up, then drops to LED 2 as the output settles
near +5 dBu. The GR meter climbs
to LED 7 (about 17 to 21 dB) and falls back over the release.

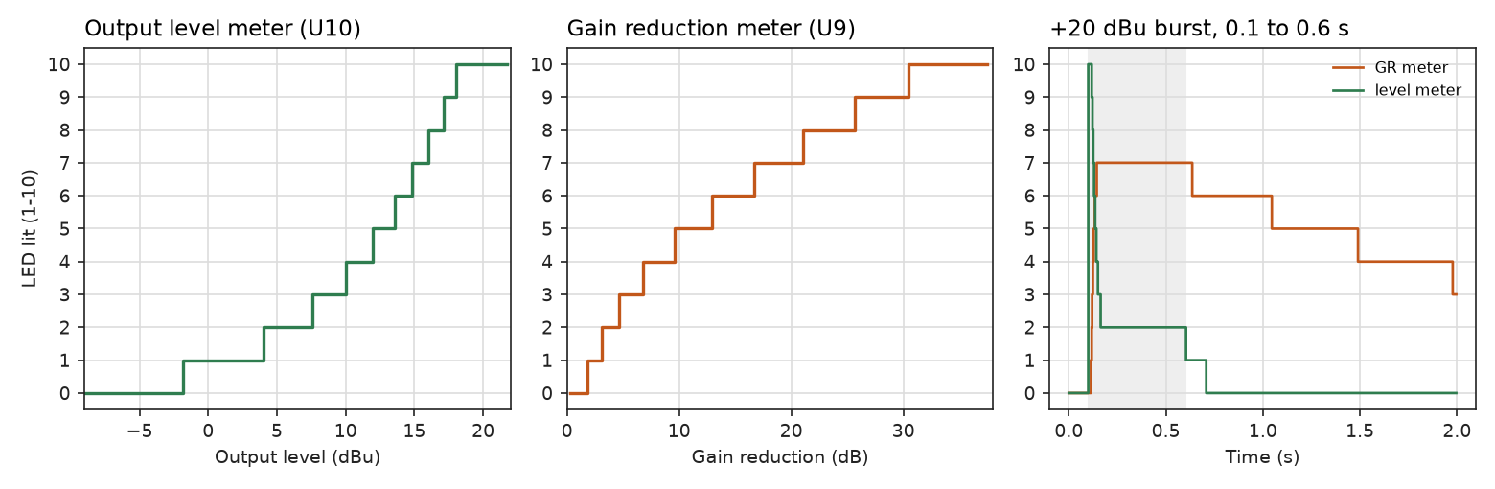
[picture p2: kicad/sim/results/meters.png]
The meters


### What still misses

1. **Most gain reduction is 36 dB, not 40 dB.** The input stage clips at about +23 dBu on
   ±16 V, so 40 dB would need a threshold near −30 dBu. Better to restate the target.
2. **The slowest attack is 71 ms and the slowest release 3.5 s**, against 50 ms and 2.2 s.
   RV5 and RV6 are the nearest values Altronics stocks (10k and 1M); a 4k7 and a 500k from
   elsewhere give 34 ms and 1.8 s. Both ranges still cover the targets at their fast ends.
3. **Times depend on level.** They are the time to 63% of the change in gain for a −10 to
   +20 dBu burst at half threshold (about 0 dBu), so about 20 dB over. Harder hits are faster.
4. **The ratio rises with level.** With RATIO at the hard end the knee is soft: about 4:1 just
   above the threshold, steeper (6:1 to 11:1) by 20 dB over.
5. **CTRL-B reaches −8.0 V at the most reduction, not −10 V.** Set the gain-reduction meter's
   RV7 against a measured CTRL-B.
6. **Supply current is about 72 / 62 mA at rest** (README says about 60 mA). That includes
   6 mA for each LM3914. A lit meter LED adds about 10 to 12 mA on +16 V (see the meters
   below), so with one LED lit in each meter +16 V is about 94 mA, inside the rack's 130 mA.
7. **C22 (fixed).** C22 filters the reference for STA only. When CTRL-B pulled the shared
   reference node down, STA lagged STB by about 60 ms, so the gain kept falling after the
   control voltage had settled: up to 20 dB of overshoot on a fast attack. At 4u7 it is about
   1 dB.

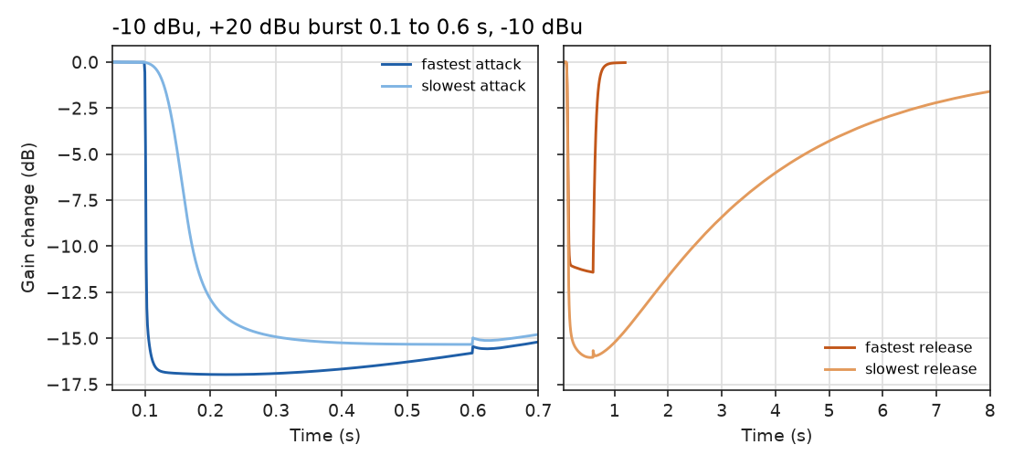
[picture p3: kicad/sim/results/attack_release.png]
Attack and release


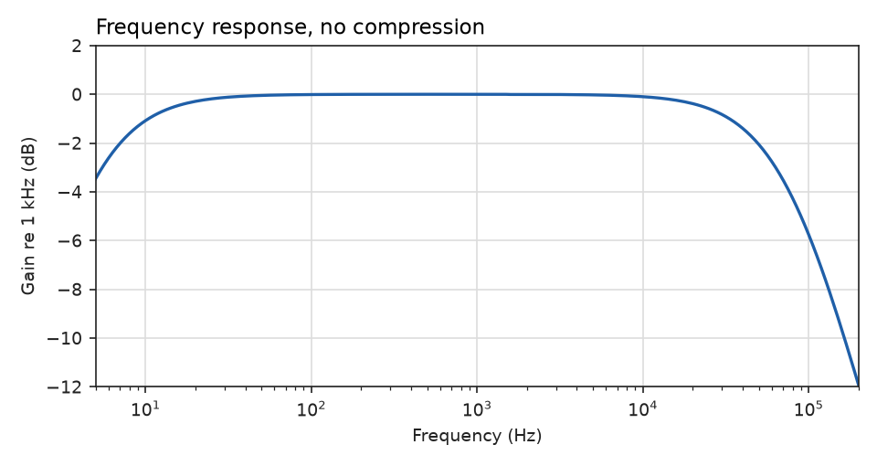
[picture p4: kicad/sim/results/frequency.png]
Frequency response


### To check by hand before ordering

- **Pot direction.** On the usual convention pin 3 is the clockwise end of a pot. RV4's
  outer pins are swapped on the sheets and the front board, so if that holds for the RK09K,
  RATIO turns clockwise for a harder ratio. THRESHOLD is still wired the other way from the
  site's guide: clockwise raises the threshold. Swapping RV3 too would need a reverse-log (C)
  taper. MAKEUP, ATTACK and RELEASE turn the expected way.
- **Parts.** `bom/altronics.csv` lists every part, with the film capacitors and the 0.1%
  R61/R62 from element14.

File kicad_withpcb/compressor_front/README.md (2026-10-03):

# Compressor front board

A 35 × 110 mm board that sits flat behind the faceplate and carries everything on the
panel: the five pots, the four toggles, and both LED meters with their two LM3914
drivers. It joins the main board with a 30-way ribbon from J1 here to J2 on the main board,
pin for pin, with the same net names in both schematics.

The parts are the ones drawn in the main schematic. They stay drawn there (excluded from
that board and its BOM) so the circuit still reads as one piece.

## How it sits

- The front of the board faces the panel. Pots, toggles, LEDs, the driver ICs and their
  small parts all go on the front.
- J1 (a plain 2×15 pin header) and C38 (47 µF, too tall for the front) go on the back.
- The toggles are Salecom mini toggles from Altronics: S1350 (DPDT) for BYPASS, S1315 (SPDT)
  for KEY, HPF and LINK. Their body stands 10.4 mm off the board and the Altronics 9 mm pots
  stand 10.6 mm, so the board sits **about 10.6 mm behind the panel**, with the pot bodies
  against the back of the panel and the toggles 0.2 mm short of it.
- Alps RK09K pots, if you use them instead, are shorter: make up the difference with a nut
  behind the panel, which may need the longer bushing version.
- The LEDs need spacers to reach the panel: about 7.8 mm for the 2 mm flat-tops drawn here
  (10.6 mm gap less the 2.8 mm LED).
- Each meter is a column of ten LEDs on a 3.0 mm pitch, so the LED bodies are 0.2 mm apart.
  The LED footprints' courtyards and silkscreen are trimmed to suit (DRC lists them as
  differing from the library). 3 mm LEDs no longer fit.
- The pots' 5 mm bushing leaves under 2 mm of thread through a 3.18 mm panel: see
  `panel/README.md` on panel thickness. The toggles' 8.9 mm bushing is plenty.
- The pins of all four toggles come through the back by about 0.8 mm.
- The main board's front edge is set back 24 mm from the panel to clear this board, the
  header and the ribbon plug. The board's back face is now about 12.2 mm behind the panel,
  so check the plug on J1 still clears it, especially with single-way sockets (taller than
  an IDC plug).

## Joining the boards

The boards are joined only by the ribbon; each one is fixed to the faceplate on its own.

- **Ribbon:** 30-way, 2.54 mm pitch, with an IDC socket crimped on each end. Main board
  J2 is a shrouded box header; J1 here is a plain pin header, so it isn't keyed. Put the
  red stripe on pin 1 at both ends (pin 1 is marked on the back silkscreen).
  Altronics has no 30-way IDC parts, so `bom/altronics.csv` lists a plain 2×15 header for
  J2 as well and a 150 mm socket-to-socket strip of single-way leads (P1023) for the ribbon.
  It works, but nothing keys it: keep lead 1 on pin 1 at both ends. For a proper IDC ribbon,
  buy the box header, two sockets and cable from element14.
- **Length:** about 150 mm, folded once between the boards. J2 sits roughly 30 mm behind
  the panel and about 35 mm higher than J1, and the sideways distance depends on where the
  main board sits in your rack, so lay the boards out and check before crimping.
- **Front board to panel:** the nuts on the five pot and four toggle bushings.
- **Main board to panel:** an L-bracket from the back of the panel to H1 and H2, the two
  M3 holes by the main board's front edge (85 mm apart). The front edge is 24 mm behind
  the panel, so the bracket leg along the board needs to reach that far: 25 × 25 mm
  aluminium angle, or a short angle with standoffs. H2 is plated and tied to CHASSIS
  (J1 pin 1), so the bracket also grounds the panel as the faceplate guide asks. Mask
  the anodise where the bracket touches the panel.

## Coordinates

The panel outline and every hole are drawn on User.Drawings, with the grid origin on the
panel's top-left corner. The board editor's coordinates read the same as the panel
drawing, and `panel/make_panel.py` takes its hole positions from this board.

## 3D models

Every part has a 3D model, so the 3D viewer and a STEP export (for the Fusion 360 assembly)
show both boards complete.

- Most come from KiCad's own library.
- The pots use Alps' official RK09K1130 model. It's the maker's file, so it isn't kept in
  git: run `sh tools/get_3d_models.sh` once to fetch it into `3dmodels/`. The pots use a
  project copy of the stock RK09K footprint that points at it.
- The toggles use simple models built to the Altronics drawings by
  `tools/make_toggle_models.py` (case, bushing, lever and pins).
- The main board's edge fingers are copper, not a part, so J1 there has no model.

## Check before ordering

- **The toggle footprints follow the drawings on Altronics' S1315 and S1350 pages:** pins on
  4.70 mm, 1.3 mm holes, the DPDT's two rows 4.83 mm apart. The S1332 (centre off) has the
  same drawing as the S1315, so it drops into any SPDT position. Check one switch against the
  footprint before ordering boards.
- The toggles sit at x = 7.15 and 30.95 mm (panel coordinates), 0.25 mm in from the old
  sub-miniature positions, so the S1350's 11.4 mm body stays on the board. The pot footprint's
  courtyard was trimmed to its pads so it doesn't overlap the S1350's.
- **The Altronics 9 mm pots (R19xx)** have the RK09K's pin and lug pattern (lugs 8.6 mm apart,
  pins 7.0 mm behind them), so they use the same footprint. Their drawing doesn't place the
  shaft relative to the lugs; the RK09K's is 0.5 mm beyond them. Check before cutting the panel.
- SW3 (HPF) and SW4 (LINK) are single-pole in the schematic and use the SPDT footprint's
  top and centre pins; the bottom pin is unused.
- There are no mounting holes: the nine bushing nuts hold the board. Add standoffs if it
  flexes.

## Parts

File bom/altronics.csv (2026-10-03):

Board | References | Value | Qty fitted | Altronics code | Altronics description | Pack size | Order (packs) | Unit price inc GST | Line total inc GST | Stock (delivery / Auburn NSW) on 2026-10-03 | Notes | If not at Altronics
front | C36 C37 | 100n | 2 | R2931 | 0.1uF 50V X7R 5mm monolithic ceramic | 1 | 20 | 0.30 | 6.00 | IN / IN
front | C38 | 47u | 1 | R5104 | 47uF 25V electrolytic | 1 | 5 | 0.50 | 2.50 | IN / IN
front | J1 | MAIN BOARD | 1 | P5410 | 40 way x 2 header pin strip (cut to 2 x 15) | 1 | 1 | 1.20 | 1.20 | IN / IN | Altronics has no 30-way box header or IDC socket (their boxed headers go 26, 34, 40). A plain 2 x 15 header fits both footprints; one 2 x 40 strip covers both boards. | 30-way IDC box header, two IDC sockets and 30-way cable from element14
front | R89 R91 | 2k7 | 2 | R7568 | 2k7 0.25W 1% metal film resistor, pk 10 | 10 | 1 | 1.30 | 1.30 | IN / IN
front | R90 | 8k2 | 1 | R7580 | 8k2 0.25W 1% metal film resistor, pk 10 | 10 | 1 | 1.30 | 1.30 | IN / IN
front | R92 | 4k7 | 1 | R7574 | 4k7 0.25W 1% metal film resistor, pk 10 | 10 | 1 | 1.30 | 1.30 | IN / IN
front | RV2 RV5 | 10k | 2 | R1946 | 10k lin 18T spline 9mm single vertical PCB pot | 1 | 2 | 4.55 | 9.10 | IN / IN | 9 mm vertical, 18T spline. Same pins and lugs as the RK09K footprint (lugs 8.6 mm apart, pins 7.0 mm behind them); body stands 10.6 mm off the board. Altronics doesn't dimension the shaft: check it lines up with the panel hole before cutting.
front | RV3 | 100kA | 1 | R1960 | 100k log 18T spline 9mm single vertical PCB pot | 1 | 1 | 4.55 | 4.55 | IN / IN | 9 mm vertical, 18T spline. Same pins and lugs as the RK09K footprint (lugs 8.6 mm apart, pins 7.0 mm behind them); body stands 10.6 mm off the board. Altronics doesn't dimension the shaft: check it lines up with the panel hole before cutting.
front | RV4 | 100k | 1 | R1948 | 100k lin 18T spline 9mm single vertical PCB pot | 1 | 1 | 4.55 | 4.55 | IN / IN | 9 mm vertical, 18T spline. Same pins and lugs as the RK09K footprint (lugs 8.6 mm apart, pins 7.0 mm behind them); body stands 10.6 mm off the board. Altronics doesn't dimension the shaft: check it lines up with the panel hole before cutting.
front | RV6 | 1M | 1 | R1950 | 1M lin 18T spline 9mm single vertical PCB pot | 1 | 1 | 4.55 | 4.55 | IN / IN | 9 mm vertical, 18T spline. Same pins and lugs as the RK09K footprint (lugs 8.6 mm apart, pins 7.0 mm behind them); body stands 10.6 mm off the board. Altronics doesn't dimension the shaft: check it lines up with the panel hole before cutting.
front | SW1 | BYPASS | 1 | S1350 | Salecom DPDT PCB mount mini toggle | 1 | 1 | 4.60 | 4.60 | IN / IN | BYPASS. DPDT on-on.
front | SW2 | INT/EXT | 1 | S1315 | Salecom SPDT PCB mount mini toggle | 1 | 3 | 2.95 | 8.85 | IN / IN | INT/EXT. SPDT on-on (S1332 centre-off fits the same footprint).
front | SW3 | HPF DEFEAT | 1 | S1315 | Salecom SPDT PCB mount mini toggle | 1 | see SW2 |  |  | IN / IN | HPF DEFEAT. SPDT on-on (S1332 centre-off fits the same footprint).
front | SW4 | LINK | 1 | S1315 | Salecom SPDT PCB mount mini toggle | 1 | see SW2 |  |  | IN / IN | LINK. SPDT on-on (S1332 centre-off fits the same footprint).
front | U9 U10 | LM3914 | 2 | Z2670 | LM3914 LED bar/dot driver (linear) | 1 | 2 | 9.10 | 18.20 | LOW / LOW (in stock only at Cannington WA) | Both meters (U10 was an LM3915, which nobody stocks). Low stock: order early or call the store.
front | D20 D21 D22 D23 D24 D25 D26 D27 D28 D29 D35 D36 D37 | meter | 13 | NOT STOCKED |  |  |  |  |  |  | Meter LED, 2 mm round flat-top, amber. The ten-LED meters sit on a 3.0 mm pitch, too tight for Altronics' 3 mm flangeless LEDs (they fitted the old seven-LED meters at 3.5 mm), and Altronics has no 2 mm LEDs. | 2 mm round flat-top LEDs (4.0 x 2.8 mm base, 2.54 mm leads) from element14 / DigiKey: GR D20-D29 amber; LVL D30-D34 green, D35-D37 amber, D38-D39 red (not checked)
front | D30 D31 D32 D33 D34 | meter | 5 | NOT STOCKED |  |  |  |  |  |  | Meter LED, 2 mm round flat-top, green. The ten-LED meters sit on a 3.0 mm pitch, too tight for Altronics' 3 mm flangeless LEDs (they fitted the old seven-LED meters at 3.5 mm), and Altronics has no 2 mm LEDs. | 2 mm round flat-top LEDs (4.0 x 2.8 mm base, 2.54 mm leads) from element14 / DigiKey: GR D20-D29 amber; LVL D30-D34 green, D35-D37 amber, D38-D39 red (not checked)
front | D38 D39 | meter | 2 | NOT STOCKED |  |  |  |  |  |  | Meter LED, 2 mm round flat-top, red. The ten-LED meters sit on a 3.0 mm pitch, too tight for Altronics' 3 mm flangeless LEDs (they fitted the old seven-LED meters at 3.5 mm), and Altronics has no 2 mm LEDs. | 2 mm round flat-top LEDs (4.0 x 2.8 mm base, 2.54 mm leads) from element14 / DigiKey: GR D20-D29 amber; LVL D30-D34 green, D35-D37 amber, D38-D39 red (not checked)
main | C1 C2 | 22u | 2 | R6570B | 22uF 50V bipolar electrolytic | 1 | 4 | 1.10 | 4.40 | IN / LOW | Bipolar, as the design asks. Check its diameter against the 6.3 mm outline.
main | C3 C4 | 1n | 2 | R2900A | 0.001uF 50V X7R 5mm monolithic ceramic | 1 | 4 | 0.40 | 1.60 | IN / IN
main | C6 C16 C17 | 100u | 3 | R5124 | 100uF 25V electrolytic | 1 | 5 | 0.55 | 2.75 | IN / IN
main | C7 C20 C23 C24 C25 C26 C27 C28 C29 C30 C31 C32 C33 C34 C41 C42 | 100n | 16 | R2931 | 0.1uF 50V X7R 5mm monolithic ceramic | 1 | see C36 |  |  | IN / IN
main | C11 C13 | 100p | 2 | R2822 | 100pF 50V SL 5mm ceramic | 1 | 4 | 0.20 | 0.80 | IN / IN | SL class ceramic; Altronics has no 100pF NP0 leaded part.
main | C18 | 10n | 1 | R2910A | 0.01uF 50V X7R 5mm monolithic ceramic | 1 | 3 | 0.40 | 1.20 | IN / IN
main | C19 C21 | 47u | 2 | R5104 | 47uF 25V electrolytic | 1 | see C38 |  |  | IN / IN
main | C22 | 4u7 | 1 | R4748 | 4.7uF 63V 105C electrolytic | 1 | 3 | 0.30 | 0.90 | IN / IN | C22, electrolytic in the design.
main | D5 D6 D7 D11 D12 | 1N4148 | 5 | Z0101 | 1N914/1N4148 small signal diode | 1 | 7 | 0.15 | 1.05 | IN / IN
main | D8 D9 | 1N4004 | 2 | Z0109 | 1N4004 400V 1A diode | 1 | 4 | 0.20 | 0.80 | IN / IN
main | D10 | BZX79-C5V1 | 1 | Z0614 | 5V1 1N4733 1W zener | 1 | 3 | 1.75 | 5.25 | IN / IN | 1N4733 is the 1 W part in a DO-41 body (fits the 7.62 mm footprint; leads 0.81 mm in 0.8 mm holes, ream to 1.0 if tight). Altronics has no 500 mW 5V1. | BZX79-C5V1 from element14
main | J2 | FRONT BOARD | 1 | P5410 | 40 way x 2 header pin strip (cut to 2 x 15) | 1 | see J1 |  |  | IN / IN | Altronics has no 30-way box header or IDC socket (their boxed headers go 26, 34, 40). A plain 2 x 15 header fits both footprints; one 2 x 40 strip covers both boards. | 30-way IDC box header, two IDC sockets and 30-way cable from element14
main | LED1 | GR | 1 | Z0733 | Yellow 50mcd 3mm flangeless LED | 1 | 3 | 0.40 | 1.20 | IN / IN | GR indicator, 3 mm. Yellow standing in for amber.
main | Q1 Q2 Q3 Q4 Q5 Q6 Q7 Q8 Q9 | BC549C | 9 | Z1044 | BC549 NPN TO-92 | 1 | 50 | 0.50 | 25.00 | IN / IN | Q1/Q2 a matched pair, Q6-Q9 a matched quad, glued together: buy a batch and sort by Vbe. Altronics does not state the gain group (the design wants BC549C).
main | R1 R2 R3 R4 R23 R24 R80 R81 R82 R83 | 22k | 10 | R7590 | 22k 0.25W 1% metal film resistor, pk 10 | 10 | 3 | 1.30 | 3.90 | IN / IN | Wants matching (0.1% or better as a ratio): buy extra and sort with a meter. R1-R4, R23/R24, R80-R83 set input and recovery CMRR.
main | R5 R6 R28 R32 R33 R34 R52 | 100R | 7 | R7534 | 100R 0.25W 1% metal film resistor, pk 10 | 10 | 1 | 1.30 | 1.30 | IN / IN
main | R7 | 8k2 | 1 | R7580 | 8k2 0.25W 1% metal film resistor, pk 10 | 10 | see R90 |  |  | IN / IN
main | R8 | 75R | 1 | R7531 | 75R 0.25W 1% metal film resistor, pk 10 | 10 | 1 | 1.30 | 1.30 | IN / IN
main | R9 | 68k | 1 | R7602 | 68k 0.25W 1% metal film resistor, pk 10 | 10 | 1 | 1.30 | 1.30 | IN / IN
main | R10 | 11k | 1 | R7583 | 11k 0.25W 1% metal film resistor, pk 10 | 10 | 1 | 1.30 | 1.30 | LOW / IN
main | R11 R12 R19 R20 R29 R30 R39 R40 R41 R43 R84 R85 R86 R94 | 10k | 14 | R7582 | 10k 0.25W 1% metal film resistor, pk 10 | 10 | 2 | 1.30 | 2.60 | IN / IN
main | R13 R14 R15 R45 | 220R | 4 | R7542 | 220R 0.25W 1% metal film resistor, pk 10 | 10 | 1 | 1.30 | 1.30 | IN / BO
main | R16 R17 | 4k7 | 2 | R7574 | 4k7 0.25W 1% metal film resistor, pk 10 | 10 | see R92 |  |  | IN / IN
main | R18 | 1k5 | 1 | R7562 | 1k5 0.25W 1% metal film resistor, pk 10 | 10 | 1 | 1.30 | 1.30 | IN / IN
main | R21 R22 | 6k8 | 2 | R7578 | 6k8 0.25W 1% metal film resistor, pk 10 | 10 | 1 | 1.30 | 1.30 | IN / IN | Wants matching (0.1% or better as a ratio): buy extra and sort with a meter. R21/R22 set thump rejection.
main | R26 R35 R38 R68 R87 | 1k | 5 | R7558 | 1k 0.25W 1% metal film resistor, pk 10 | 10 | 1 | 1.30 | 1.30 | IN / IN
main | R31 R49 | 5k1 | 2 | R7575 | 5k1 0.25W 1% metal film resistor, pk 10 | 10 | 1 | 1.30 | 1.30 | IN / IN
main | R36 | 82k | 1 | R7604 | 82k 0.25W 1% metal film resistor, pk 10 | 10 | 1 | 1.30 | 1.30 | LOW / IN
main | R37 | 47k | 1 | R7598 | 47k 0.25W 1% metal film resistor, pk 10 | 10 | 1 | 1.30 | 1.30 | IN / IN
main | R42 R44 | 20k | 2 | R7589 | 20k 0.25W 1% metal film resistor, pk 10 | 10 | 1 | 1.30 | 1.30 | IN / IN
main | R46 | 47R | 1 | R7526 | 47R 0.25W 1% metal film resistor, pk 10 | 10 | 1 | 1.30 | 1.30 | IN / IN
main | R47 | 15k | 1 | R7586 | 15k 0.25W 1% metal film resistor, pk 10 | 10 | 1 | 1.30 | 1.30 | IN / IN
main | R50 R51 | 10R | 2 | R7510 | 10R 0.25W 1% metal film resistor, pk 10 | 10 | 1 | 1.30 | 1.30 | IN / IN
main | R53 | 1k8 | 1 | R7564 | 1k8 0.25W 1% metal film resistor, pk 10 | 10 | 1 | 1.30 | 1.30 | IN / IN
main | R60 | 24k | 1 | R7591 | 24k 0.25W 1% metal film resistor, pk 10 | 10 | 1 | 1.30 | 1.30 | LOW / IN
main | R69 | 36k | 1 | R7595 | 36k 0.25W 1% metal film resistor, pk 10 | 10 | 1 | 1.30 | 1.30 | IN / IN
main | R74 | 220k | 1 | R7614 | 220k 0.25W 1% metal film resistor, pk 10 | 10 | 1 | 1.30 | 1.30 | IN / IN
main | R77 | 3k9 | 1 | R7572 | 3k9 0.25W 1% metal film resistor, pk 10 | 10 | 1 | 1.30 | 1.30 | IN / IN
main | R88 | 100k | 1 | R7606 | 100k 0.25W 1% metal film resistor, pk 10 | 10 | 1 | 1.30 | 1.30 | IN / IN
main | R93 | 18k | 1 | R7588 | 18k 0.25W 1% metal film resistor, pk 10 | 10 | 1 | 1.30 | 1.30 | IN / IN
main | RV1 | 2k | 1 | R2378A | 2k 3296W top adjust 25 turn trimpot | 1 | 3 | 3.15 | 9.45 | IN / IN
main | RV7 RV8 | 20k | 2 | R2384A | 20k 3296W top adjust 25 turn trimpot | 1 | 4 | 3.15 | 12.60 | IN / IN
main | U1 U2 U3 U5 U6 U7 | NE5532 | 6 | Z2785 | NE5532AP dual op amp | 1 | 7 | 3.50 | 24.50 | IN / IN | Socketed (P0550).
main | U4 | TL072 | 1 | Z2872 | TL072 dual JFET op amp | 1 | 2 | 2.20 | 4.40 | IN / IN | U4, socketed (P0550).
main | C5 C8 | 10u | 2 | NOT STOCKED |  |  |  |  |  |  | 10u film. Altronics film stops at 1.0uF (R3037B MKT) at 5 mm pitch, and its 2.2uF film is a 27 mm greencap. The main board is drawn for the element14 part named here. | element14 3518951: TDK B32562H1106K000, 10uF 63V PET, 15 mm pitch, 16.5 x 11.8 x 13 mm. $8.86 each, 538 in stock (UK, 3-5 days)
main | C9 C10 | 4u7 | 2 | NOT STOCKED |  |  |  |  |  |  | 4u7 film. Altronics film stops at 1.0uF (R3037B MKT) at 5 mm pitch, and its 2.2uF film is a 27 mm greencap. The main board is drawn for the element14 part named here. | element14 4457285: TDK B32562H1475K000, 4.7uF 100V PET, 15 mm pitch, 16.5 x 7.3 x 10.6 mm. $5.23 each (min 5), 880 in stock (UK, 3-5 days)
main | C14 C35 | 2u2 | 2 | NOT STOCKED |  |  |  |  |  |  | 2u2 film. Altronics film stops at 1.0uF (R3037B MKT) at 5 mm pitch, and its 2.2uF film is a 27 mm greencap. The main board is drawn for the element14 part named here. | element14 2429330: KEMET MMK5225K63J06L4BULK, 2.2uF 63V PET, 5 mm pitch, 7.2 x 7.2 x 13 mm. $1.19 each (min 10), 884 in stock, not being restocked
main | C15 | 10u | 1 | NOT STOCKED |  |  |  |  |  |  | Timing capacitor, must be film (low leakage). Altronics film stops at 1.0uF (R3037B MKT) at 5 mm pitch, and its 2.2uF film is a 27 mm greencap. The main board is drawn for the element14 part named here. | element14 3518951: TDK B32562H1106K000, 10uF 63V PET, 15 mm pitch, 16.5 x 11.8 x 13 mm. $8.86 each, 538 in stock (UK, 3-5 days)
main | R48 | 0R | 1 | NOT STOCKED |  |  |  |  |  |  | Wire link: the 0R is the PGND to AGND star link. Nothing to order.
main | R61 | 1k33 | 1 | NOT STOCKED |  |  |  |  |  |  | 1k33 0.1%. Altronics stocks E24 1% only (nearest is 1k3, R7561). Sets the gain cell rest point with R62, by absolute value. | element14 / DigiKey: 1k33 0.1% 25 ppm axial metal film, e.g. Vishay CMF55 or RN55D series (not checked)
main | R62 | 23k2 | 1 | NOT STOCKED |  |  |  |  |  |  | 23k2 0.1%, see R61. No Altronics equivalent. | element14 / DigiKey: 23k2 0.1% 25 ppm axial metal film (not checked)
hardware | J1-J2 |  | 1 | P1023 | Socket to socket 30 way prototyping ribbon strip, 150mm | 1 | 1 | 5.20 | 5.20 | IN / IN | Board-to-board ribbon: 30 single-way sockets each end, 150 mm. Unkeyed, so keep wire 1 on pin 1 at both ends. Lay the boards out first: 150 mm is an estimate.
hardware | RV2-RV6 |  | 5 | H6545 | 11 x 14mm aluminium black 18T spline knob | 1 | 5 | 3.95 | 19.75 | IN | Knobs. 11 mm across: ATTACK and RELEASE are only 15.1 mm apart, so anything over ~13 mm clashes.
hardware | U1-U7 |  | 10 | P0550 | 8 pin 0.3in DIL tinned IC socket | 1 | 10 | 0.35 | 3.50 | IN / IN | DIP-8 sockets for the op amps (the footprints are socket outlines). The LM391x go in direct: sockets would foul the meter LEDs.
hardware | bracket |  | 1 | H3110A | M3 x 6mm pan pozi nickel bolt, pk 25 | 25 | 1 | 2.55 | 2.55 | IN / IN | M3 screws for the L-bracket to H1/H2 and the panel.
hardware | bracket |  | 1 | H3175 | M3 hex nut, pk 25 | 25 | 1 | 2.65 | 2.65 | IN / IN | M3 nuts.
hardware | bracket |  | 1 | NOT STOCKED | 25 x 25 mm aluminium angle, ~40 mm long |  |  |  |  |  |  | hardware store
hardware | panel |  | 1 | NOT STOCKED | Faceplate 38.10 x 133.35 x 3.18 mm aluminium, from panel/faceplate.dxf |  |  |  |  |  |  | panel shop
 |  |  |  |  | Altronics total, inc GST, excluding postage |  |  |  | 232.65 | checked 2026-10-03

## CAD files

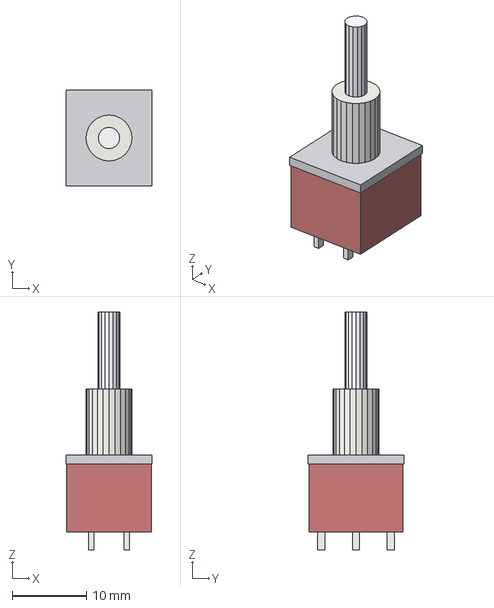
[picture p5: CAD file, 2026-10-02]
kicad_withpcb/compressor_front/3dmodels/SW_Toggle_Mini_DPDT_Salecom_S1350.step
11.6 x 12.9 x 32.1 mm

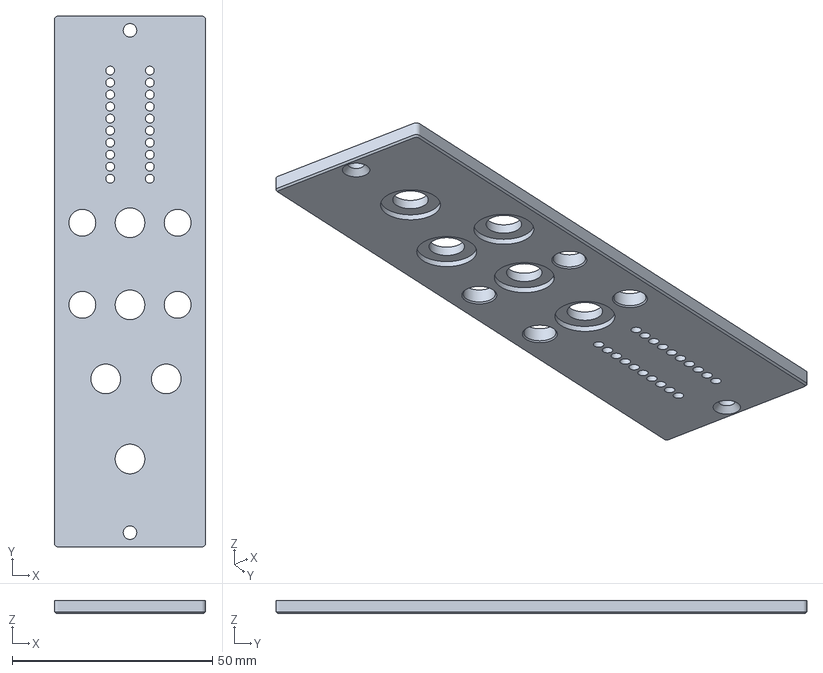
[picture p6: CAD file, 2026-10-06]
panel/print/faceplate-multicolor.3mf
37.8 x 132.6 x 3.20 mm

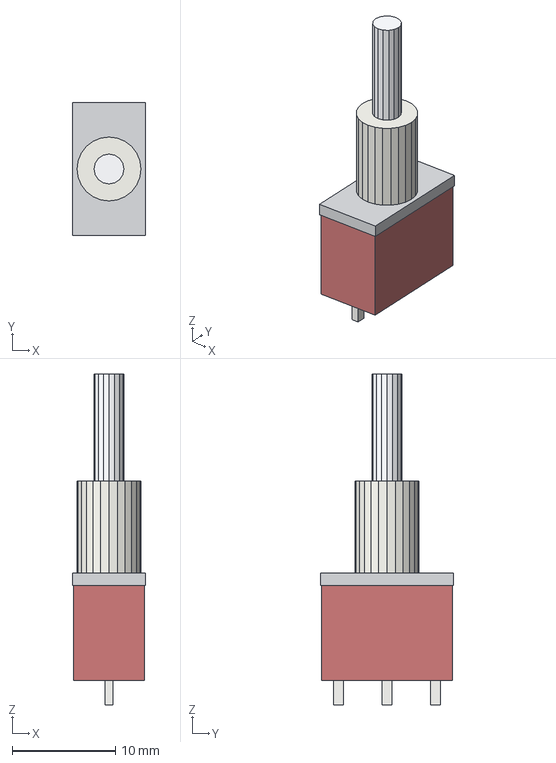
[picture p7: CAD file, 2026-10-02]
kicad_withpcb/compressor_front/3dmodels/SW_Toggle_Mini_SPDT_Salecom_S1315.step
7.10 x 12.9 x 32.1 mm

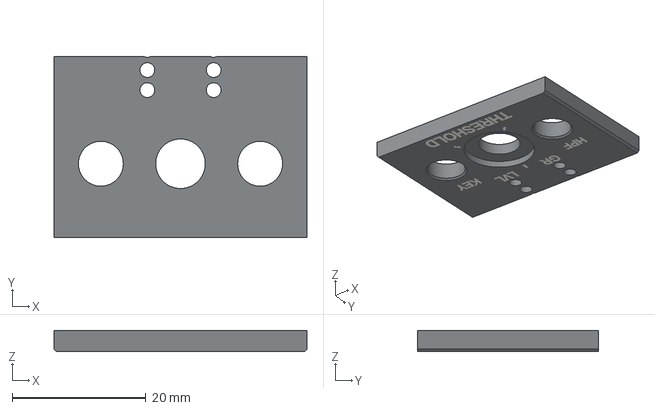
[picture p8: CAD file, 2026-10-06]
panel/print/faceplate-fit-test-multicolor-prusaslicer.3mf
37.8 x 27.0 x 3.20 mm

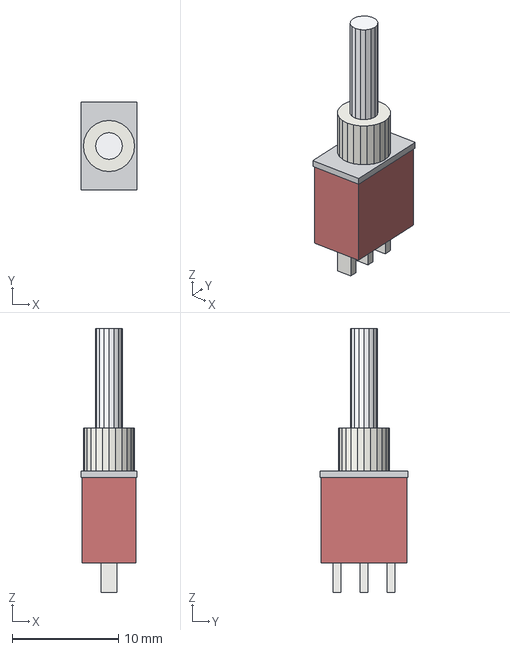
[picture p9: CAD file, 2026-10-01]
kicad_withpcb/compressor_front/3dmodels/SW_Toggle_SubMini_SPDT_Jaycar_ST0300.step
5.28 x 8.33 x 24.9 mm

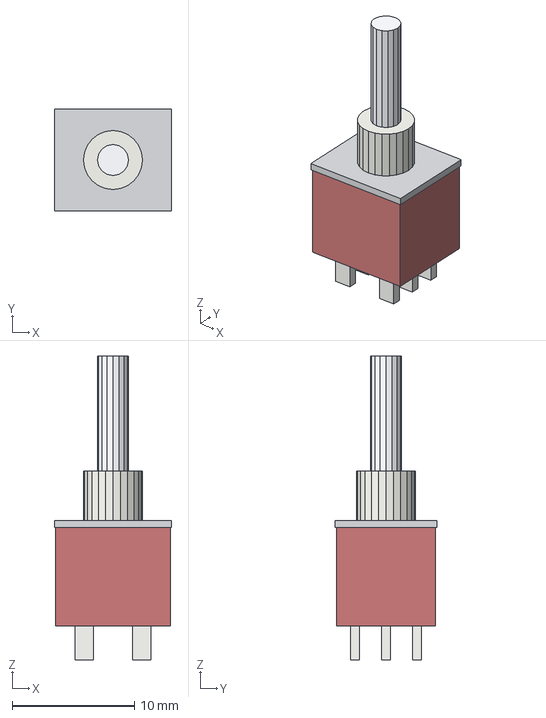
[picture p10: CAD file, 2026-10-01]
kicad_withpcb/compressor_front/3dmodels/SW_Toggle_SubMini_DPDT_Jaycar_ST0310.step
9.60 x 8.33 x 24.9 mm

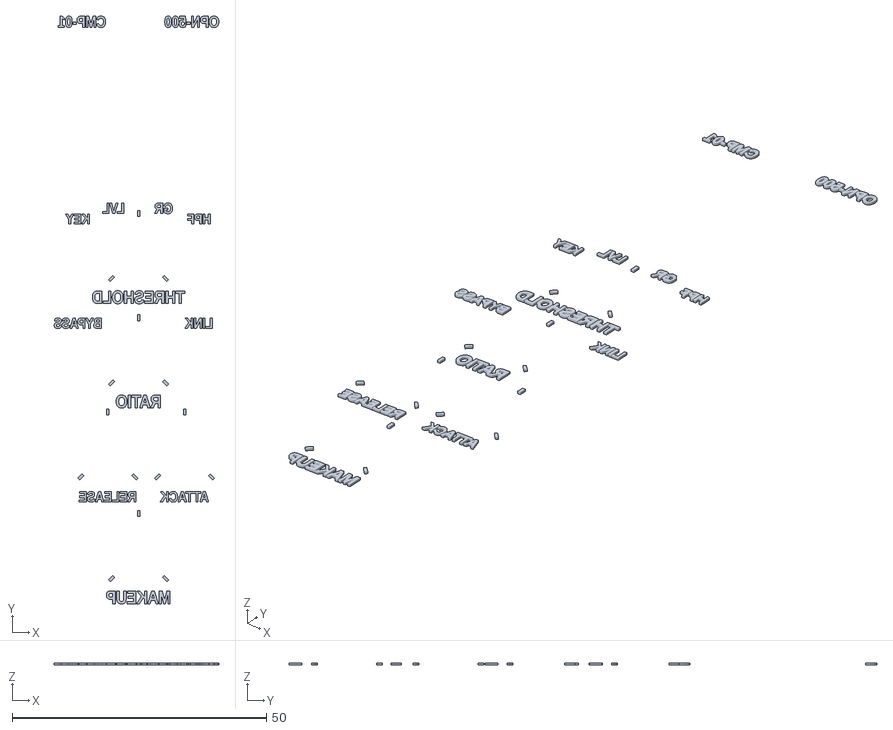
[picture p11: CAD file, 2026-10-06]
panel/print/faceplate-legend.stl
32.4 x 115.6 x 0.4

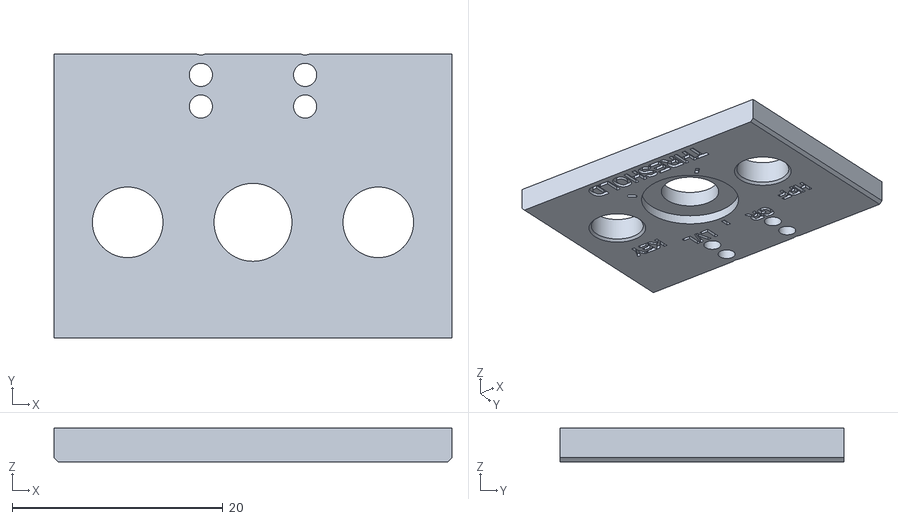
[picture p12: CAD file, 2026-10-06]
panel/print/faceplate-fit-test.stl
37.8 x 27.0 x 3.20

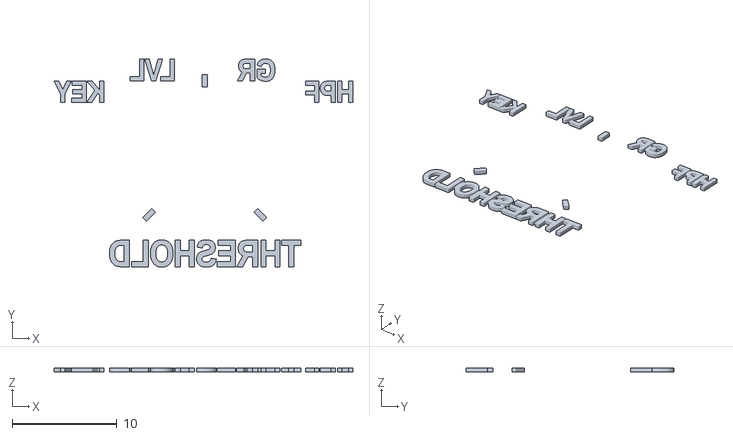
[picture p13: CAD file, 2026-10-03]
panel/print/faceplate-fit-legend.stl
28.5 x 19.9 x 0.4

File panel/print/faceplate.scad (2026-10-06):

// 3D-printable faceplate for the OPN-500 / CMP-01 compressor.
//
// Hole positions and legends come from panel_data.scad, which make_panel.py writes
// from the same definition as the drawing and the DXF. Everything here is how to print
// it: thicknesses, fit allowances and the engraving.
//
// Printed face down: the front face sits on the bed, so it comes out as smooth (or as
// textured) as the build plate, and the legend is engraved into it. Nothing needs
// supports.
//
//   part = "panel"        the faceplate
//   part = "legend"       the engraving as a separate body, to print in a second colour
//   part = "fit_test"     a 27 mm strip through THRESHOLD, HPF, KEY and the meter
//                         bottoms, to check the fits before printing the whole panel
//   part = "fit_legend"   the fit test's engraving
//   part = "preview"      both, front face up, in colour (for the picture in README.md)
//
// openscad -o faceplate.stl -D 'part="panel"' faceplate.scad   (or run build.sh)

include <panel_data.scad>

part = "panel";

/* [Outline] */
// printed width; nominal is 38.10, trimmed so it slides in beside its neighbours
trim_w = 37.8;
// printed height; nominal is 133.35
trim_h = 132.6;
corner_r = 1.0;
// 45 degree chamfer round the front face, so first-layer squish doesn't flare the edge
edge_chamfer = 0.4;

/* [Thickness] */
// overall, as the 1/8 inch metal panel, so the rack screws and every part behind the
// panel sit exactly as drawn
thk = 3.2;
// left under each pot nut: the 9 mm pots' 5 mm bushing needs the panel this thin
pot_web = 2.0;
// counterbore on the front round each pot, for the nut and washer; the knob covers it
pot_well_d = 12.5;

/* [Fits] */
// added to the pot, switch and screw holes; FDM holes print undersize
hole_comp = 0.2;
// meter windows; the LEDs sit behind the panel, so these only let the light out
led_d = 2.2;
// chamfer on the bed side of pot, switch and screw holes
hole_chamfer = 0.3;

/* [Legend] */
legend_depth = 0.4;
// 1.0 = the mockup's type sizes, which are too small for a 0.4 mm nozzle
legend_scale = 1.3;
// squeeze the type horizontally to keep the ATTACK / RELEASE row apart
legend_condense = 0.85;
// grows every stroke by this much on each side
legend_bold = 0.05;
legend_font = "Liberation Sans:style=Bold";
// tick marks at the start, middle and end of each pot's travel
ticks = true;
tick_w = 0.5;
tick_len = 1.2;
// gap between the knob skirt and the inner end of a tick
tick_gap = 0.9;

/* [Fit test strip] */
fit_y0 = 36;
fit_y1 = 63;

$fn = 96;
eps = 0.01;

// panel coordinates (y down from the top-left of the front) to model coordinates
// (y up, front face on top at z = thk). The print orientation flips it at the end.
function P(x, y) = [x, H - y];

// ------------------------------------------------------------------ legend
// OpenSCAD's size is close to the font's ascent; the mockup's numbers are SVG font
// sizes. 0.8 brings the cap heights level with the mockup at legend_scale 1.
module legend_2d() {
    for (t = LEGENDS) {
        a = t[4] == "start" ? "left" : t[4] == "end" ? "right" : "center";
        translate(P(t[1], t[2]))
            scale([legend_condense, 1])
                offset(delta = legend_bold)
                    text(t[0], size = t[3] * 0.8 * legend_scale, font = legend_font,
                         halign = a, valign = "baseline");
    }
    if (ticks)
        for (p = POTS) {
            r0 = p[4] / 2 + tick_gap;
            // the mockup's scale runs 270 degrees from bottom left over the top
            for (a = [135, 270, 405])
                translate(P(p[1], p[2]))
                    rotate(-a)
                        translate([r0, -tick_w / 2]) square([tick_len, tick_w]);
        }
}

module legend_body() {
    translate([0, 0, thk - legend_depth])
        linear_extrude(legend_depth + eps) legend_2d();
}

// ------------------------------------------------------------------ blank
module rounded_rect(w, h, r) {
    offset(r = r) offset(delta = -r) square([w, h]);
}

module blank() {
    x0 = (W - trim_w) / 2;
    y0 = (H - trim_h) / 2;
    translate([x0, y0, 0])
        hull() {
            linear_extrude(thk - edge_chamfer) rounded_rect(trim_w, trim_h, corner_r);
            linear_extrude(thk)
                translate([edge_chamfer, edge_chamfer])
                    rounded_rect(trim_w - 2 * edge_chamfer, trim_h - 2 * edge_chamfer,
                                 max(corner_r - edge_chamfer, 0.01));
        }
}

// ------------------------------------------------------------------ holes
// a through hole of diameter d, chamfered c deep on the front face
module through(x, y, d, c = hole_chamfer) {
    translate(concat(P(x, y), [-1])) {
        cylinder(d = d, h = thk + 2);
        translate([0, 0, 1 + thk - c]) cylinder(d1 = d, d2 = d + 2 * c + 2 * eps, h = c + eps);
    }
}

module holes() {
    for (p = POTS) {
        through(p[1], p[2], p[3] + hole_comp);
        translate(concat(P(p[1], p[2]), [pot_web])) cylinder(d = pot_well_d, h = thk);
    }
    for (s = SWITCHES) through(s[1], s[2], s[3] + hole_comp);
    for (l = LEDS) through(l[1], l[2], led_d, 0);
    for (m = MTG) {
        d = MTG_D + hole_comp;
        // 82 degree countersink on the front face
        csk_h = (CSINK_D - d) / 2 / tan(41);
        through(m[0], m[1], d, 0);
        // the cone starts just inside the hole, so its edge never lands on the
        // hole's own edge (which leaves a non-manifold seam in the mesh)
        sink = 0.05;
        translate(concat(P(m[0], m[1]), [thk - csk_h - sink]))
            cylinder(d1 = d - 2 * sink * tan(41), d2 = CSINK_D + 2 * eps * tan(41),
                     h = csk_h + sink + eps);
    }
}

module panel() {
    difference() {
        blank();
        holes();
        legend_body();
    }
}

module legend() {
    intersection() {
        blank();
        difference() { legend_body(); holes(); }
    }
}

// ------------------------------------------------------------------ fit test
module fit_window() {
    translate([-1, H - fit_y1, -1]) cube([W + 2, fit_y1 - fit_y0, thk + 2]);
}

// ------------------------------------------------------------------ output
// flipped face down, with the panel's top edge at +y and its corner at the origin
module print_orient() {
    translate([W, 0, thk]) rotate([0, 180, 0]) children();
}

if (part == "preview") {
    color("#2a2f33") panel();
    color("#f2efe7") translate([0, 0, 0.02]) legend();  // lifted clear of the face
} else print_orient()
    if (part == "panel") panel();
    else if (part == "legend") legend();
    else if (part == "fit_test") intersection() { panel(); fit_window(); }
    else if (part == "fit_legend") intersection() { legend(); fit_window(); }

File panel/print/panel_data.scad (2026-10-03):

// Written by make_panel.py: do not edit. Change make_panel.py and re-run it.
// Panel coordinates: origin at the top-left corner of the front face, x right,
// y down, millimetres.

W = 38.100;
H = 133.350;
THK = 3.180;
MTG_D = 3.180;
CSINK_D = 5.720;
MTG = [[19.050, 3.960], [19.050, 129.390]];
FRONT_BOARD = [1.550, 12.000, 36.550, 122.000];  // x0, y0, x1, y1

POTS = [
    ["RV3", 19.050, 52.000, 7.200, 12.000],
    ["RV4", 19.050, 72.500, 7.200, 12.000],
    ["RV5", 10.000, 91.000, 7.200, 12.000],
    ["RV6", 25.100, 91.000, 7.200, 12.000],
    ["RV2", 19.050, 111.000, 7.200, 12.000]
];
SWITCHES = [
    ["SW3", 7.150, 52.000, 6.500],
    ["SW2", 30.950, 52.000, 6.500],
    ["SW4", 7.150, 72.500, 6.500],
    ["SW1", 30.950, 72.500, 6.500]
];
LEDS = [
    ["D20", 14.100, 14.000, 2.200],
    ["D21", 14.100, 17.000, 2.200],
    ["D22", 14.100, 20.000, 2.200],
    ["D23", 14.100, 23.000, 2.200],
    ["D24", 14.100, 26.000, 2.200],
    ["D25", 14.100, 29.000, 2.200],
    ["D26", 14.100, 32.000, 2.200],
    ["D27", 14.100, 35.000, 2.200],
    ["D28", 14.100, 38.000, 2.200],
    ["D29", 14.100, 41.000, 2.200],
    ["D39", 24.000, 14.000, 2.200],
    ["D38", 24.000, 17.000, 2.200],
    ["D37", 24.000, 20.000, 2.200],
    ["D36", 24.000, 23.000, 2.200],
    ["D35", 24.000, 26.000, 2.200],
    ["D34", 24.000, 29.000, 2.200],
    ["D33", 24.000, 32.000, 2.200],
    ["D32", 24.000, 35.000, 2.200],
    ["D31", 24.000, 38.000, 2.200],
    ["D30", 24.000, 41.000, 2.200]
];
LEGENDS = [
    ["OPN-500", 3.200, 7.900, 2.150, "start"],
    ["CMP-01", 34.900, 7.900, 2.150, "end"],
    ["GR", 14.100, 44.500, 2.000, "middle"],
    ["LVL", 24.000, 44.500, 2.000, "middle"],
    ["THRESHOLD", 19.050, 62.200, 2.450, "middle"],
    ["RATIO", 19.050, 82.700, 2.450, "middle"],
    ["ATTACK", 10.000, 101.200, 2.000, "middle"],
    ["RELEASE", 25.100, 101.200, 2.000, "middle"],
    ["MAKEUP", 19.050, 121.200, 2.450, "middle"],
    ["HPF", 7.150, 46.550, 1.950, "middle"],
    ["KEY", 30.950, 46.550, 1.950, "middle"],
    ["LINK", 7.150, 67.050, 1.950, "middle"],
    ["BYPASS", 30.950, 67.050, 1.950, "middle"]
];

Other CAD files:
panel/print/faceplate.stl
panel/print/faceplate-multicolor-prusaslicer.3mf
panel/print/faceplate-fit-test-multicolor.3mf
panel/faceplate.dxf

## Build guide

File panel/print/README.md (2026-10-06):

# 3D-printed faceplate

A faceplate you can print on an ordinary FDM printer, for anyone without a laser cutter,
CNC or panel shop. Same holes and legends as the `toggle` layout in [`../`](../README.md),
so it fits the front board as drawn.

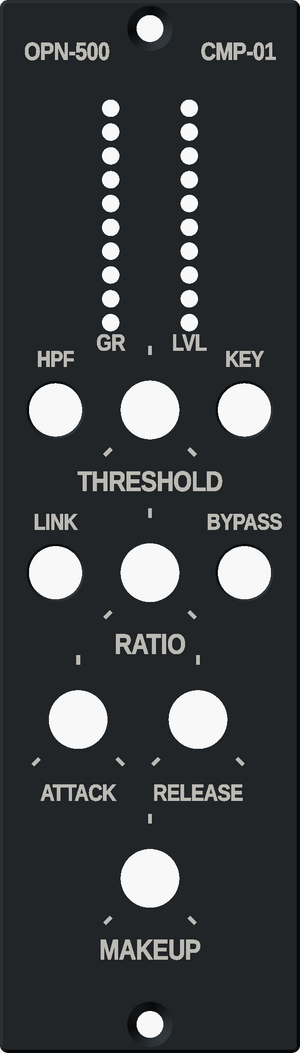
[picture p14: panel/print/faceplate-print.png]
Printed faceplate, front


| File | What it is |
|---|---|
| `faceplate-multicolor.3mf` | Panel and legend as one object with two parts, for a two-colour print in Bambu Studio or OrcaSlicer. |
| `faceplate-multicolor-prusaslicer.3mf` | The same for PrusaSlicer, which keeps its part table in a different file. |
| `faceplate-fit-test-multicolor.3mf`, `-prusaslicer.3mf` | The same pair for the fit test. |
| `faceplate.stl` | The faceplate, already flipped face down for printing. |
| `faceplate-legend.stl` | The engraved legend and pot ticks as their own body, for a second colour. |
| `faceplate-fit-test.stl` | A 27 mm strip across THRESHOLD, HPF, KEY and the bottom of both meters. |
| `faceplate-fit-legend.stl` | The fit test's legend. |
| `faceplate.scad` | The model. Every print setting is a parameter at the top. |
| `panel_data.scad` | Hole positions and legend text, written by `make_panel.py`. Don't edit it. |
| `build.sh` | Re-runs `make_panel.py`, exports all four STLs (a few minutes) and builds the 3MFs. |
| `make_3mf.py` | Combines each panel and legend STL into the two 3MFs. |

## What's different from the metal panel

- **Thickness:** 3.2 mm, the same as the 1/8″ metal panel, so the rack screws and everything
  behind the panel sit exactly where the front board expects. The back is flat.
- **Pot wells:** each pot hole has a 12.5 mm counterbore on the front, 1.2 mm deep. That leaves
  2.0 mm of plastic under the nut, which gives the 9 mm pots' short bushing about 3 mm of
  thread for the washer and nut (the metal panel needed thinning here for the same reason).
  The 11 mm knobs sit over the wells.
- **Fit allowance:** pot, toggle and screw holes print 0.2 mm larger than drawn
  (`hole_comp`), because FDM holes come out undersize. The meter holes stay 2.2 mm: the LEDs
  sit behind the panel, so those holes only let the light out, and keeping them small keeps
  0.8 mm of plastic between neighbours.
- **Width and height:** 37.8 × 132.6 mm rather than the nominal 38.10 × 133.35, so it slides in
  beside the next module. The front edge has a 0.4 mm chamfer so first-layer squish doesn't
  flare it.
- **Legend:** engraved 0.4 mm into the front, 30% larger than on the mockup (the mockup's
  1.4 to 1.7 mm capitals are too fine for a 0.4 mm nozzle). Each pot gets three ticks: start,
  middle and end of travel.

## Printing it

1. **Print the fit test first.** It's a short print. Check that a pot and a toggle drop
   through their holes, the pot nut sits inside its well, and the LEDs line up behind the
   meter holes. If a hole is tight or loose, change `hole_comp` in `faceplate.scad` and run
   `./build.sh` (or open the file in OpenSCAD and use the Customizer).
2. **Material:** PETG in black or dark grey. A light colour lets each meter LED glow through
   the thin walls on either side of its hole. PETG over PLA because a rack runs warm and
   PLA slowly gives way under a tightened nut.
3. **Settings:** 0.4 mm nozzle, 0.2 mm layers, 4 walls, 100% infill, no supports. Print it as
   exported, face down. A textured PEI sheet gives the front a nice finish.
4. **Two colours (optional):** in Bambu Studio or OrcaSlicer, import `faceplate-multicolor.3mf`
   (File, Import, or Cmd/Ctrl+I); in PrusaSlicer use `faceplate-multicolor-prusaslicer.3mf`.
   It loads as one object with two parts already lined up: the panel on filament 1 and the
   legend on filament 2. Pick a dark filament for 1 and a light one for 2. The file carries no
   print settings, so opening it as a project in Bambu Studio says it is loading geometry
   only; that's expected. Both colours share the first two layers, so it needs a multicolour
   unit (AMS, MMU) or a second nozzle, but it only swaps on those two layers.
   With one colour, print `faceplate.stl` and fill the engraving afterwards with paint or a
   white wax crayon rubbed in and wiped off.

## Fitting it

- Snap the small anti-rotation tab off the front of each pot, as you would for a metal
  panel, or it holds the pot off the back of the panel.
- Tighten the nuts gently. Plastic creeps, and the nuts only need to hold the board.
- A plastic panel doesn't ground the pot and toggle bushings the way an anodised panel tied
  to CHASSIS does. If touching a knob adds hum, run a wire from a solder tag under one toggle's
  nut to the main board's CHASSIS (H2).

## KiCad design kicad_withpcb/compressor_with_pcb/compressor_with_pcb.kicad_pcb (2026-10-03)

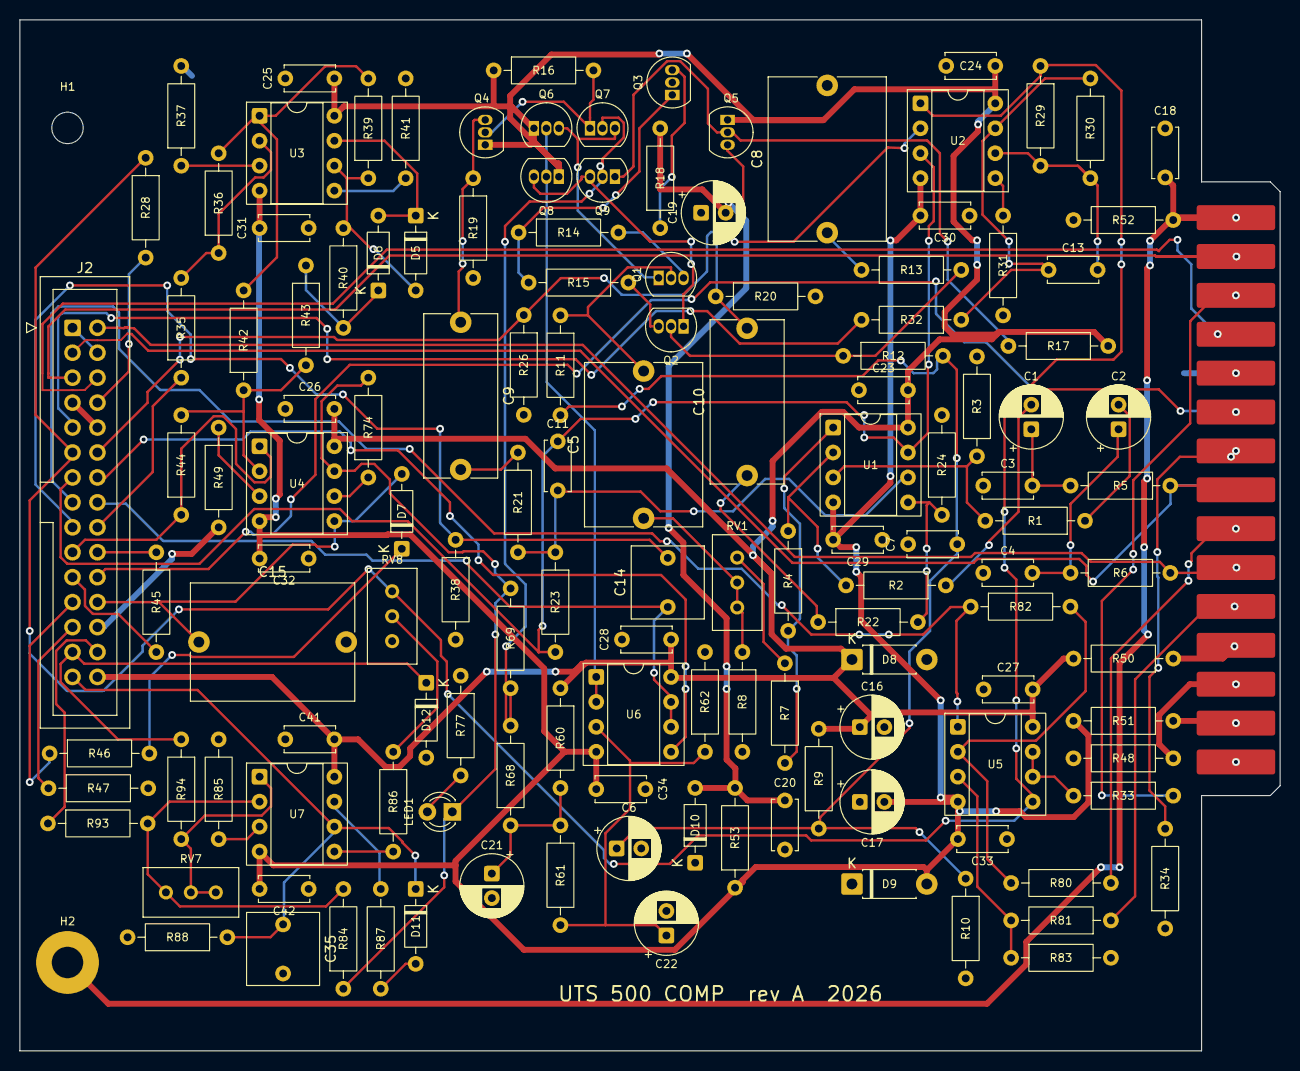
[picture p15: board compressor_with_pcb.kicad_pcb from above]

Board: 2 copper layers, 128.3 x 105.0 mm, 137 parts (0 on the bottom side), 93 nets.

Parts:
C1, C2: 22u; CP_Radial_D6.3mm_P2.50mm
C3, C4: 1n; C_Disc_D5.0mm_W2.5mm_P5.00mm
C5, C8, C15: 10u; C_Rect_L16.5mm_W11.8mm_P15.00mm_MKT
C6, C16, C17: 100u; CP_Radial_D6.3mm_P2.50mm
C7, C20, C23, C24, C25, C26, C27, C28, C29, C30, C31, C32, C33, C34, C41, C42: 100n; C_Disc_D5.0mm_W2.5mm_P5.00mm
C9, C10: 4u7; C_Rect_L16.5mm_W7.3mm_P15.00mm_MKT
C11, C13: 100p; C_Disc_D5.0mm_W2.5mm_P5.00mm
C14, C35: 2u2; C_Rect_L7.2mm_W7.2mm_P5.00mm_FKS2_FKP2_MKS2_MKP2
C18: 10n; C_Disc_D5.0mm_W2.5mm_P5.00mm
C19, C21: 47u; CP_Radial_D6.3mm_P2.50mm
C22: 4u7; CP_Radial_D6.3mm_P2.50mm
D5, D6, D7, D11, D12: 1N4148; D_DO-35_SOD27_P7.62mm_Horizontal
D8, D9: 1N4004; D_DO-41_SOD81_P7.62mm_Horizontal
D10: BZX79-C5V1; D_DO-35_SOD27_P7.62mm_Horizontal
H1: Bracket M3; MountingHole_3.2mm_M3
H2: Bracket M3; MountingHole_3.2mm_M3_Pad
J1: EDA 306; EDA_306
J2: FRONT BOARD; IDC-Header_2x15_P2.54mm_Vertical
LED1: GR; LED_D3.0mm
Q1, Q2, Q3, Q4, Q5, Q6, Q7, Q8, Q9: BC549C; TO-92_Inline
R1, R2, R3, R4, R23, R24, R80, R81, R82, R83: 22k; R_Axial_DIN0207_L6.3mm_D2.5mm_P10.16mm_Horizontal
R5, R6, R28, R32, R33, R34, R52: 100R; R_Axial_DIN0207_L6.3mm_D2.5mm_P10.16mm_Horizontal
R7: 8k2; R_Axial_DIN0207_L6.3mm_D2.5mm_P10.16mm_Horizontal
R8: 75R; R_Axial_DIN0207_L6.3mm_D2.5mm_P10.16mm_Horizontal
R9: 68k; R_Axial_DIN0207_L6.3mm_D2.5mm_P10.16mm_Horizontal
R10: 11k; R_Axial_DIN0207_L6.3mm_D2.5mm_P10.16mm_Horizontal
R11, R12, R19, R20, R29, R30, R39, R40, R41, R43, R84, R85, R86, R94: 10k; R_Axial_DIN0207_L6.3mm_D2.5mm_P10.16mm_Horizontal
R13, R14, R15, R45: 220R; R_Axial_DIN0207_L6.3mm_D2.5mm_P10.16mm_Horizontal
R16, R17: 4k7; R_Axial_DIN0207_L6.3mm_D2.5mm_P10.16mm_Horizontal
R18: 1k5; R_Axial_DIN0207_L6.3mm_D2.5mm_P10.16mm_Horizontal
R21, R22: 6k8; R_Axial_DIN0207_L6.3mm_D2.5mm_P10.16mm_Horizontal
R26, R35, R38, R68, R87: 1k; R_Axial_DIN0207_L6.3mm_D2.5mm_P10.16mm_Horizontal
R31, R49: 5k1; R_Axial_DIN0207_L6.3mm_D2.5mm_P10.16mm_Horizontal
R36: 82k; R_Axial_DIN0207_L6.3mm_D2.5mm_P10.16mm_Horizontal
R37: 47k; R_Axial_DIN0207_L6.3mm_D2.5mm_P10.16mm_Horizontal
R42, R44: 20k; R_Axial_DIN0207_L6.3mm_D2.5mm_P10.16mm_Horizontal
R46: 47R; R_Axial_DIN0207_L6.3mm_D2.5mm_P10.16mm_Horizontal
R47: 15k; R_Axial_DIN0207_L6.3mm_D2.5mm_P10.16mm_Horizontal
R48: 0R; R_Axial_DIN0207_L6.3mm_D2.5mm_P10.16mm_Horizontal
R50, R51: 10R; R_Axial_DIN0207_L6.3mm_D2.5mm_P10.16mm_Horizontal
R53: 1k8; R_Axial_DIN0207_L6.3mm_D2.5mm_P10.16mm_Horizontal
R60: 24k; R_Axial_DIN0207_L6.3mm_D2.5mm_P10.16mm_Horizontal
R61: 1k33; R_Axial_DIN0207_L6.3mm_D2.5mm_P10.16mm_Horizontal
R62: 23k2; R_Axial_DIN0207_L6.3mm_D2.5mm_P10.16mm_Horizontal
R69: 36k; R_Axial_DIN0207_L6.3mm_D2.5mm_P10.16mm_Horizontal
R74: 220k; R_Axial_DIN0207_L6.3mm_D2.5mm_P10.16mm_Horizontal
R77: 3k9; R_Axial_DIN0207_L6.3mm_D2.5mm_P10.16mm_Horizontal
R88: 100k; R_Axial_DIN0207_L6.3mm_D2.5mm_P10.16mm_Horizontal
R93: 18k; R_Axial_DIN0207_L6.3mm_D2.5mm_P10.16mm_Horizontal
RV1: 2k; Potentiometer_Bourns_3296W_Vertical
RV7, RV8: 20k; Potentiometer_Bourns_3296W_Vertical
U1, U2, U3, U5, U6, U7: NE5532; DIP-8_W7.62mm_Socket
U4: TL072; DIP-8_W7.62mm_Socket

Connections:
+16V: C16.1, C23.1, C24.1, C25.1, C26.1, C27.1, C28.1, C41.1, D8.1 (K), J2.30, Q4.1 (C), Q5.1 (C), Q6.1 (C), Q8.1 (C), R9.2, R16.1, R17.1, R50.2, R60.1, U1.8 (V+), U2.8 (V+), U3.8 (V+), U4.8 (V+), U5.8 (V+), U6.8 (V+), U7.8 (V+)
+16V-IN: J1.12, R50.1
-5V1: C19.2, C20.1, D10.2 (A), R18.2, R53.2
-16V: C17.2, C29.1, C30.1, C31.1, C32.1, C33.1, C34.1, C42.1, D9.2 (A), R51.2, R53.1, U1.4 (V-), U2.4 (V-), U3.4 (V-), U4.4 (V-), U5.4 (V-), U6.4 (V-), U7.4 (V-)
-16V-IN: J1.14, R51.1
AGND: C3.2, C4.2, C6.2, C7.2, C8.2, C15.2, C16.2, C17.1, C18.2, C19.1, C20.2, C21.2, C22.2, C23.2, C24.2, C25.2, C26.2, C27.2, C28.2, C29.2, C30.2, C31.2, C32.2, C33.2, C34.2, C35.2, C41.2, C42.2, D8.2 (A), D9.1 (K), D10.1 (K), D12.2 (A), J1.5, J2.1, J2.4, J2.7, J2.10, J2.26, Q3.2 (B), R3.2, R8.2, R10.2, R19.2, R20.2, R24.2, R26.2, R31.2, R34.1, R37.2, R38.2, R41.2, R47.2, R48.2, R49.2, R52.2, R62.2, R77.1, R83.2, R85.2, R88.2, RV8.3
ATK_W: J2.23, R46.1
AUXIN+: J1.11, R81.1
AUXIN-: J1.9, R80.1
AUXOUT+: J1.3, R33.2
AUXOUT-: J1.7, R34.2
BYP_A: J2.8, R28.2
BYP_B: J2.9, R32.2
CHASSIS: C18.1, H2.1, J1.1, R52.1
CTRL-B: LED1.1 (K), R69.2, R74.2, R84.1, U4.7
GR_METER: D12.1 (K), J2.27, R94.1
GR_REF: J2.28, R93.1
HPF_A: C14.1, J2.16, U6.6 (-), U6.7
HPF_B: C14.2, J2.17, R38.1
IN+: J1.10, J2.2, R6.1
IN-: J1.8, J2.3, R5.1
KEY: J2.15, R82.1, U5.1
KEY_SRC: J2.14, U6.5 (+)
LINK: J1.6, J2.22
LINK_SW: J2.21, R45.2
LVL_METER: C35.1, D11.1 (K), J2.29, R88.1, U7.6 (-)
MAKEUP_FB: J2.12, R26.1, U2.2 (-)
unnamed: C1.1, C3.1, R5.2
unnamed: C1.2, R2.1
unnamed: C2.1, C4.1, R6.2
unnamed: C2.2, R1.1
unnamed: C8.1, R13.2
unnamed: C9.2, R21.1
unnamed: C10.1, R22.1
unnamed: C13.1, R30.1, R32.1, U2.7
unnamed: C21.1, R60.2, R61.1, R68.1
unnamed: D5.2 (A), R39.1, R40.1, U3.6 (-)
unnamed: D5.1 (K), D6.2 (A), U3.7
unnamed: D6.1 (K), R40.2, R43.1
unnamed: D7.1 (K), R46.2
unnamed: D11.2 (A), R87.1
unnamed: LED1.2 (A), R77.2
unnamed: C5.2, Q1.2 (B), R11.1
unnamed: Q1.1 (C), Q6.3 (E), Q7.3 (E)
unnamed: Q1.3 (E), R14.2
unnamed: Q2.2 (B), R12.1, R13.1
unnamed: Q2.1 (C), Q8.3 (E), Q9.3 (E)
unnamed: Q2.3 (E), R15.1
unnamed: Q3.1 (C), R14.1, R15.2
unnamed: Q3.3 (E), R18.1
unnamed: Q4.2 (B), Q7.1 (C), R16.2
unnamed: C9.1, Q4.3 (E), R19.1
unnamed: Q5.2 (B), Q9.1 (C), R17.2
unnamed: C10.2, Q5.3 (E), R20.1
unnamed: R4.2, R7.2, U1.1
unnamed: R7.1, RV1.1
unnamed: R36.2, R39.2, R42.2, U3.1
unnamed: R86.1, RV8.2
unnamed: R87.2, U7.7
unnamed: R94.2, RV7.2, RV7.3, U7.1
unnamed: R1.2, R3.1, U1.3 (+)
unnamed: R2.2, R4.1, U1.2 (-)
unnamed: R22.2, R24.1, U1.5 (+)
unnamed: C11.1, R21.2, R23.1, U1.6 (-)
unnamed: R31.1, U2.5 (+)
unnamed: C13.2, R29.2, R30.2, U2.6 (-)
unnamed: R37.1, U3.3 (+)
unnamed: R35.2, R36.1, U3.2 (-)
unnamed: R41.1, U3.5 (+)
unnamed: R49.1, U4.3 (+)
unnamed: R42.1, R43.2, R44.2, U4.2 (-)
unnamed: R74.1, U4.6 (-)
unnamed: R81.2, R83.1, U5.3 (+)
unnamed: R80.2, R82.2, U5.2 (-)
unnamed: R33.1, U5.6 (-), U5.7
unnamed: C22.1, R61.2, R62.1, U6.3 (+)
unnamed: R85.1, U7.3 (+)
unnamed: R84.2, R93.2, RV7.1, U7.2 (-)
unnamed: R86.2, U7.5 (+)
OUT+: J1.2, J2.5
OUT-: J1.4, J2.6
OUT-A: J2.11, R28.1, R29.1, RV8.1, U2.1, U5.5 (+)
PAD: C5.1, R8.1, RV1.2, RV1.3
PGND: J1.13, R48.1
RATIO_CW: J2.19, R44.1, U4.1
RATIO_W: J2.20, R45.1
REL_W: J2.25, R47.1
SIG-VCA: C11.2, J2.13, R23.2, U1.7, U2.3 (+)
STA: Q6.2 (B), Q8.2 (B), U6.1, U6.2 (-)
STB: Q7.2 (B), Q9.2 (B), R68.2, R69.1
THR_W: J2.18, R35.1
TIMING: C15.1, D7.2 (A), J2.24, U4.5 (+)
VBIAS: C6.1, C7.1, R9.1, R10.1, R11.2, R12.2

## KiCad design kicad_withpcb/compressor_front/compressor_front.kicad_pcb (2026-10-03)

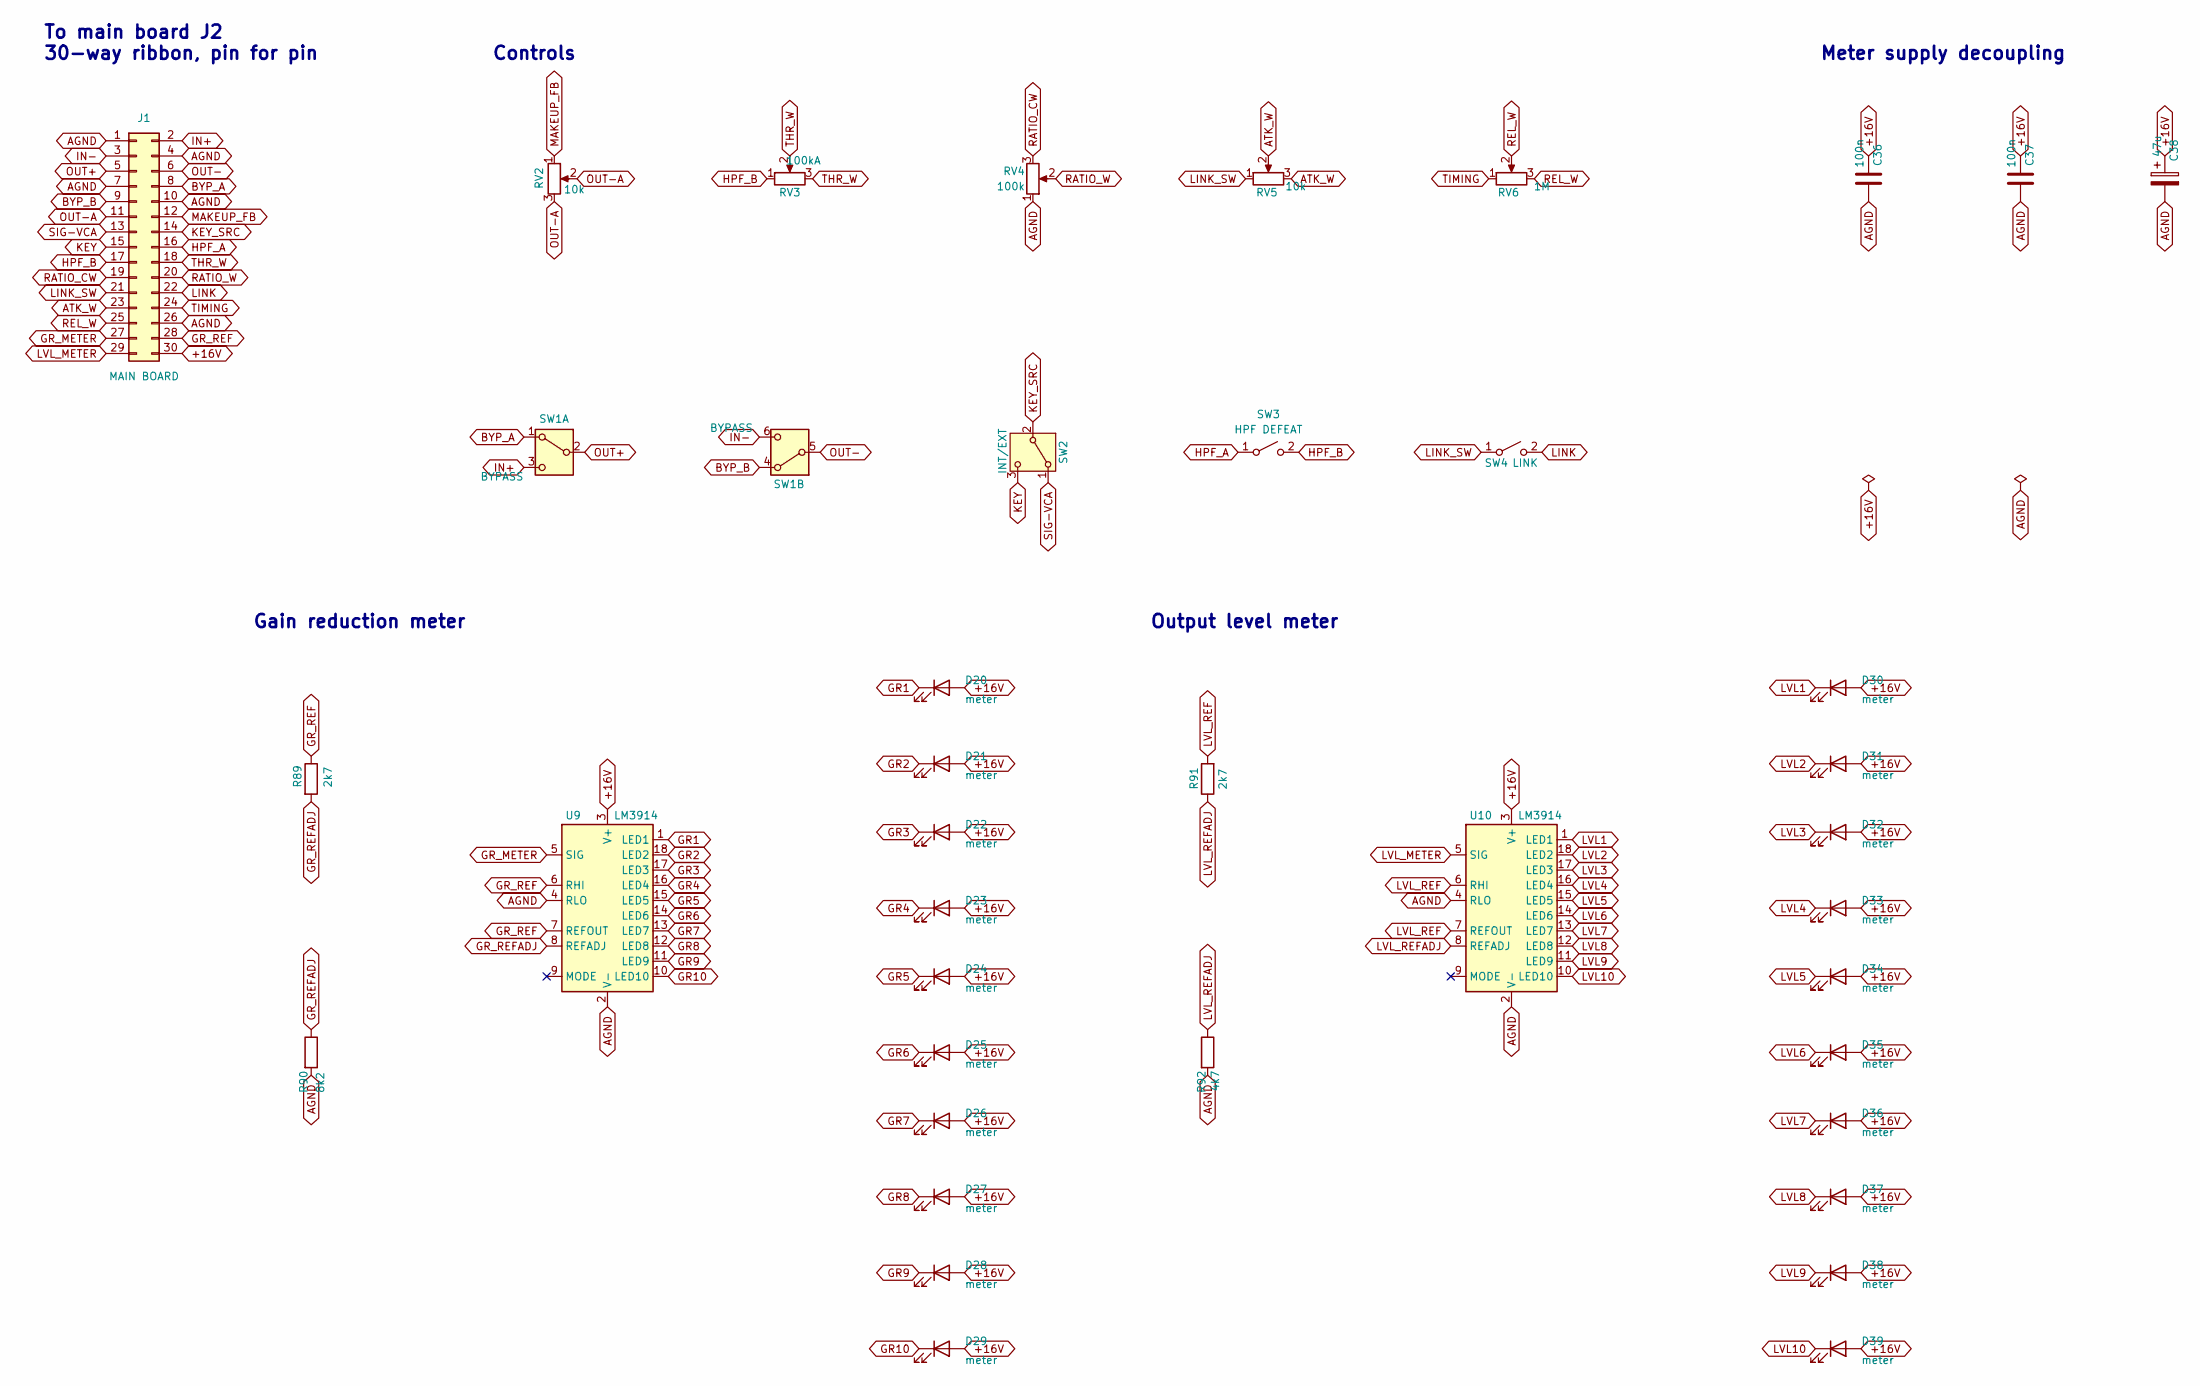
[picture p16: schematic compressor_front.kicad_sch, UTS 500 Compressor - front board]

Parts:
C36, C37: 100n; C_Disc_D5.0mm_W2.5mm_P5.00mm
C38: 47u; CP_Radial_D6.3mm_P2.50mm
D20, D21, D22, D23, D24, D25, D26, D27, D28, D29, D30, D31, D32, D33, D34, D35, D36, D37, D38, D39: meter; LED_D2.0mm_W4.0mm_H2.8mm_FlatTop
J1: MAIN BOARD; PinHeader_2x15_P2.54mm_Vertical
R89, R91: 2k7; R_Axial_DIN0207_L6.3mm_D2.5mm_P10.16mm_Horizontal
R90: 8k2; R_Axial_DIN0207_L6.3mm_D2.5mm_P7.62mm_Horizontal
R92: 4k7; R_Axial_DIN0207_L6.3mm_D2.5mm_P7.62mm_Horizontal
RV2, RV5: 10k; Potentiometer_Alps_RK09K_Single_Vertical
RV3: 100kA; Potentiometer_Alps_RK09K_Single_Vertical
RV4: 100k; Potentiometer_Alps_RK09K_Single_Vertical
RV6: 1M; Potentiometer_Alps_RK09K_Single_Vertical
SW1: BYPASS; SW_Toggle_Mini_DPDT_Salecom_S1350
SW2: INT/EXT; SW_Toggle_Mini_SPDT_Salecom_S1315
SW3: HPF DEFEAT; SW_Toggle_Mini_SPDT_Salecom_S1315
SW4: LINK; SW_Toggle_Mini_SPDT_Salecom_S1315
U9, U10: LM3914; DIP-18_W7.62mm

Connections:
+16V: C36.1, C37.1, C38.1, D20.2 (A), D21.2 (A), D22.2 (A), D23.2 (A), D24.2 (A), D25.2 (A), D26.2 (A), D27.2 (A), D28.2 (A), D29.2 (A), D30.2 (A), D31.2 (A), D32.2 (A), D33.2 (A), D34.2 (A), D35.2 (A), D36.2 (A), D37.2 (A), D38.2 (A), D39.2 (A), J1.30, U9.3 (V+), U10.3 (V+)
AGND: C36.2, C37.2, C38.2, J1.1, J1.4, J1.7, J1.10, J1.26, R90.2, R92.2, RV4.1, U9.2 (V-), U9.4 (RLO), U10.2 (V-), U10.4 (RLO)
ATK_W: J1.23, RV5.2, RV5.3
BYP_A: J1.8, SW1.1 (A)
BYP_B: J1.9, SW1.4 (A)
GR1: D20.1 (K), U9.1 (LED1)
GR2: D21.1 (K), U9.18 (LED2)
GR3: D22.1 (K), U9.17 (LED3)
GR4: D23.1 (K), U9.16 (LED4)
GR5: D24.1 (K), U9.15 (LED5)
GR6: D25.1 (K), U9.14 (LED6)
GR7: D26.1 (K), U9.13 (LED7)
GR8: D27.1 (K), U9.12 (LED8)
GR9: D28.1 (K), U9.11 (LED9)
GR10: D29.1 (K), U9.10 (LED10)
GR_METER: J1.27, U9.5 (SIG)
GR_REF: J1.28, R89.1, U9.6 (RHI), U9.7 (REFOUT)
GR_REFADJ: R89.2, R90.1, U9.8 (REFADJ)
HPF_A: J1.16, SW3.1 (A)
HPF_B: J1.17, RV3.1, SW3.2 (B)
IN+: J1.2, SW1.3 (C)
IN-: J1.3, SW1.6 (C)
KEY: J1.15, SW2.3 (C)
KEY_SRC: J1.14, SW2.2 (B)
LINK: J1.22, SW4.2 (B)
LINK_SW: J1.21, RV5.1, SW4.1 (A)
LVL1: D30.1 (K), U10.1 (LED1)
LVL2: D31.1 (K), U10.18 (LED2)
LVL3: D32.1 (K), U10.17 (LED3)
LVL4: D33.1 (K), U10.16 (LED4)
LVL5: D34.1 (K), U10.15 (LED5)
LVL6: D35.1 (K), U10.14 (LED6)
LVL7: D36.1 (K), U10.13 (LED7)
LVL8: D37.1 (K), U10.12 (LED8)
LVL9: D38.1 (K), U10.11 (LED9)
LVL10: D39.1 (K), U10.10 (LED10)
LVL_METER: J1.29, U10.5 (SIG)
LVL_REF: R91.2, U10.6 (RHI), U10.7 (REFOUT)
LVL_REFADJ: R91.1, R92.1, U10.8 (REFADJ)
MAKEUP_FB: J1.12, RV2.1
OUT+: J1.5, SW1.2 (B)
OUT-: J1.6, SW1.5 (B)
OUT-A: J1.11, RV2.2, RV2.3
RATIO_CW: J1.19, RV4.3
RATIO_W: J1.20, RV4.2
REL_W: J1.25, RV6.2, RV6.3
SIG-VCA: J1.13, SW2.1 (A)
THR_W: J1.18, RV3.2, RV3.3
TIMING: J1.24, RV6.1

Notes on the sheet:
To main board J2 30-way ribbon, pin for pin
Controls
Gain reduction meter
Output level meter
Meter supply decoupling

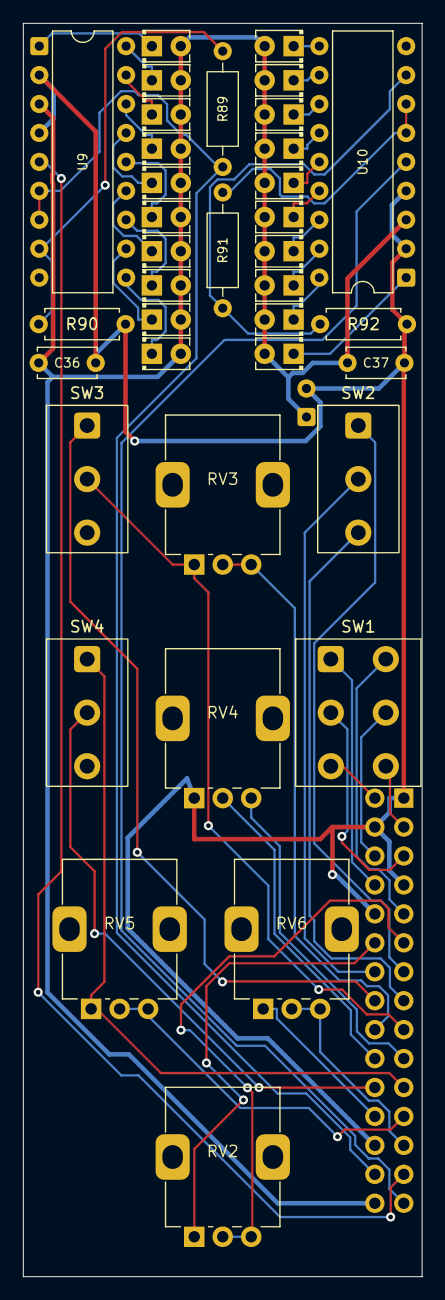
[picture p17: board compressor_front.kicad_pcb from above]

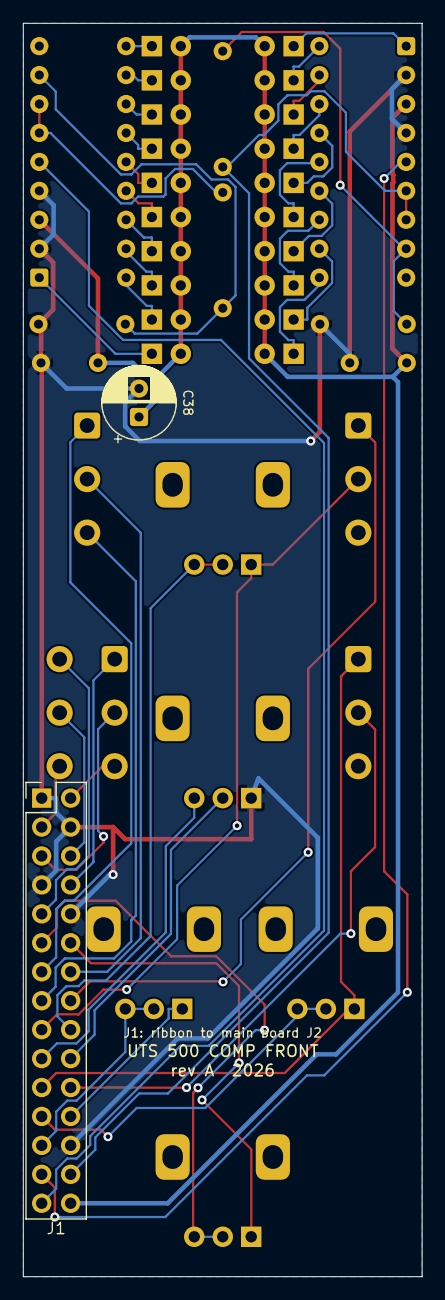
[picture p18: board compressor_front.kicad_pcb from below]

Board: 2 copper layers, 35.0 x 110.0 mm, 39 parts (2 on the bottom side), 49 nets.

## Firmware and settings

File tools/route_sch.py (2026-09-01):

#!/usr/bin/env python3
"""
route_sch.py - turn the label-wired compressor schematic into a drawn-wire one.

The approach is the one a human drafter uses, not "route everything":

  * Rails (+16V / -16V / -5V1) become power symbols at each pin.
  * Grounds (AGND / PGND / CHASSIS) become ground symbols at each pin.
  * Any net with more pins than MAX_FANOUT stays a named label - drawing 14
    wires to one node makes a schematic less readable, not more.
  * Everything left - the local signal nets - is drawn as orthogonal wire.

Routing is A* on a 1.27 mm grid with a turn penalty, so paths come out with as
few corners as possible. Occupancy is tracked per *edge*, not per cell, which
is what lets two different nets cross at right angles (legal, no junction dot)
while forbidding them to run collinearly on top of each other (illegal - it
would merge the nets).

Correctness is not assumed. After emitting the file the script asks kicad-cli for
the netlist, diffs it against design.py, and demotes any net that came out wrong
to labels - then does it again until KiCad and the design agree. A net that is
drawn is therefore drawn correctly, and one that could not be is still connected.

One KiCad rule this depends on, found by experiment and worth knowing: KiCad joins
wires only where they share an ENDPOINT. A wire running straight through a point
is NOT connected to a wire ending there, even with a junction dot on it. Every T
must be three segments meeting at a point, which is what split_at_vertices() does.

What this script does not do is place the parts well, and placement - not routing -
is what makes a schematic readable. Parts are laid out on a connectivity-ordered
grid, so the wires are short and orthogonal but the drawing does not read as signal
flow. Treat the output as a correct starting point to drag into shape in Eeschema.

Usage:  python3 route_sch.py [-o out.kicad_sch] [--fanout N] [--turn N] [--passes N]
"""
import argparse, heapq, math, os, uuid, datetime, collections
import sexp
from sexp import Q, dumps, resolve_symbol, symbol_pins
import design

# ----------------------------------------------------------------- parameters
GRID      = 1.27           # mm - every pin in this design lands on it
CELL_W    = 26             # grid units per placement cell (33.0 mm)
CELL_H    = 22             # grid units per placement cell (27.9 mm)
COLS      = 10
MARGIN    = 14             # grid units of border
STUB      = 2              # grid units of escape wire off every pin
TURN_COST = 4              # A* penalty per corner; higher = straighter, longer
MAX_POP   = 120000         # A* expansion cap per connection

RAILS   = {'+16V': 'VCC', '-16V': 'VEE', '-5V1': 'VEE'}
GROUNDS = {'AGND': 'GND', 'PGND': 'GNDD', 'CHASSIS': 'GNDA'}

NS = uuid.UUID('6ba7b810-9dad-11d1-80b4-00c04fd430c8')
# FROZEN IDENTIFIER, as in gen_project.py - see the note there before touching it.
def U(s): return str(uuid.uuid5(NS, 'steer500r:' + s))
ROOT = U('root')
PROJ = 'UTS Mini Mixing Desk - Compressor'

_sc = {}
def sym(lib, name):
    k = (lib, name)
    if k not in _sc: _sc[k] = resolve_symbol(lib, name)
    return _sc[k]

def pins_of(lib, name, unit):
    p = symbol_pins(sym(lib, name))
    out = dict(p.get(unit, {}))
    for k, v in p.get(0, {}).items(): out.setdefault(k, v)
    return out

def place_pin(px, py, X, Y, rot):
    """Symbol-space pin -> schematic mm. Verified against kicad-cli for all four
    angles (rot 90 puts Device:R pin 1 to the west, rot 270 to the east)."""
    if rot == 0:   return (X + px, Y - py)
    if rot == 90:  return (X - py, Y - px)
    if rot == 180: return (X - px, Y + py)
    return (X + py, Y + px)

def outward(ang, rot):
    """Unit vector pointing away from the symbol body, in schematic space.
    Same transform as place_pin, minus the translation."""
    a = math.radians((ang + 180) % 360)
    dx, dy = math.cos(a), math.sin(a)
    if   rot == 0:   v = (dx, -dy)
    elif rot == 90:  v = (-dy, -dx)
    elif rot == 180: v = (-dx, dy)
    else:            v = (dy, dx)
    return (int(round(v[0])), int(round(v[1])))

def label_angle(vec):
    return {(1,0):0, (0,-1):90, (-1,0):180, (0,1):270}[vec]

# ------------------------------------------------------------------ the parts
class Part:
    __slots__ = ('ref','lib','name','value','fp','block','pins','unit',
                 'X','Y','rot','gx','gy','sheet')
    def __init__(self, p):
        self.ref, self.lib, self.name, self.value, self.fp, self.block, self.pins = p[:7]
        self.unit = p[7] if len(p) > 7 else 1
        self.rot = 0

def load_parts():
    out = []
    for p in design.PARTS:
        if p[0].startswith('#'):        # PWR_FLAGs are re-created after routing
            continue
        out.append(Part(p))
    return out

def classify(parts, max_fanout):
    fan = collections.Counter()
    for p in parts:
        for net in p.pins.values(): fan[net] += 1
    kind = {}
    for net, n in fan.items():
        if net in design.NO_CONNECT:  kind[net] = 'nc'
        elif net in RAILS:            kind[net] = 'rail'
        elif net in GROUNDS:          kind[net] = 'gnd'
        elif n > max_fanout:          kind[net] = 'label'
        else:                         kind[net] = 'wire'
    return kind, fan

# ------------------------------------------------------------------ placement
def order_block(items):
    """Greedy connectivity chain: after the first part, repeatedly take whichever
    unplaced part shares the most nets with the ones already down. Keeps parts
    that talk to each other physically near each other, which is most of what
    makes the router's job easy."""
    if not items: return []
    rest = list(items)
    seq  = [rest.pop(0)]
    live = collections.Counter(seq[0].pins.values())
    while rest:
        best, bi = -1, 0
        for i, cand in enumerate(rest):
            s = sum(live[n] for n in cand.pins.values())
            if s > best: best, bi = s, i
        nxt = rest.pop(bi); seq.append(nxt)
        for n in nxt.pins.values(): live[n] += 1
    return seq

def orient(part, kind):
    """Two-pin passives: ground pin at the bottom, rail pin at the top. Costs
    nothing and removes most of the crossing wires around the supply."""
    pins = pins_of(part.lib, part.name, part.unit)
    if len(part.pins) != 2: return 0
    vert = all(abs(pins[k][0]) < 0.01 for k in part.pins if k in pins)
    if not vert: return 0
    for pn, net in part.pins.items():
        if pn not in pins: continue
        k = kind.get(net)
        top = pins[pn][1] > 0                      # symbol +y renders upward
        if k == 'gnd':  return 180 if top else 0
        if k == 'rail': return 0 if top else 180
    return 0
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

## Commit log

2026-08-31 Add files to git
    [connector.kicad_sch, input.kicad_sch, output.kicad_sch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]
2026-08-31 add Docs & fix name & all the other shit
    [UTS Mini Mixing Desk - Compressor.kicad_sch, connector.kicad_sch, input.kicad_sch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]
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2026-08-31 Add Tools, Readme & fix docs things
    [route_sch.py]
2026-08-31 Add AI Gen Faceplate (tis kinda shit tho)
    [faceplate.dxf]
2026-09-01 Fix width of docs & add mockups
    [faceplate.dxf]
2026-09-01 fix folder layout and add meter leds
    [UTS Mini Mixing Desk - Compressor.kicad_sch, connector.kicad_sch, faceplate.dxf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]
2026-09-28 Start movement to single schematic and pcb for compressor final development.
    [compressor_with_pcb.kicad_pcb, compressor_with_pcb.kicad_sch, faceplate.dxf]
2026-09-28 Add power shtuff and meters to big boy schematic
    [UTS Mini Mixing Desk - Compressor.kicad_sch, compressor_with_pcb.kicad_sch, connector.kicad_sch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]
2026-09-28 Cleanup meters & power in schematic
    [compressor_with_pcb.kicad_sch]
2026-09-28 Fix issues with schematic and basic add pcb
    [compressor_with_pcb.kicad_pcb, compressor_with_pcb.kicad_sch]
2026-09-28 Add last few footprints for switches as header pins
    [compressor_with_pcb.kicad_pcb, compressor_with_pcb.kicad_sch]
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2026-10-01 Move panel controls and meters to a front board
    Pots, switches and both meters now sit on a separate front board, as the
    faceplate fit guide recommends. They stay drawn in the schematic but are
    excluded from this board and its BOM. J2 (2x15 IDC) carries the 24 signals
    that cross, with ground between the audio pairs.
    Front edge set back 24 mm to clear the front board, and the card guide
    keep-outs are now 3 mm on both layers.
    [compressor_with_pcb.kicad_pcb, compressor_with_pcb.kicad_sch]
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2026-10-01 Place the main board by section
    Power entry by pins 12 to 14, input and output stages next to the fingers,
    the gain cell in the middle and the sidechain towards the front with J2.
    Decoupling sits against pins 8 and 4 of each op amp, and the matched pair
    and quad are placed touching, flat faces together.
    [compressor_with_pcb.kicad_pcb]
2026-10-01 Route the supply rails
    +16V, -16V and -5V1 run on the top layer in 0.6 mm from the power entry to
    each chip. PGND is a single track from pin 13 to R48, and CHASSIS stays by
    pin 1.
    [compressor_with_pcb.kicad_pcb]
2026-10-01 Route the audio path
    Balanced input and output, the input receiver and pad, the gain cell with
    its recovery amp, makeup and output drivers, and the aux in and out. The
    bypass lines run forward to J2 for the switch on the front board.
    [compressor_with_pcb.kicad_pcb]
2026-10-01 Route the sidechain and meter lines
    Detector, threshold, ratio and timing, the steering reference, and the two
    meter feeds, with the long slow runs going forward to J2.
    [compressor_with_pcb.kicad_pcb]
2026-10-01 Pour AGND on the bottom layer
    Every AGND pad is tied in with a thin track first, so nothing depends on a
    sliver of pour, then the bottom layer is poured with thermal reliefs. Three
    pads that only touched a stray island are taken off the pour and rely on
    their track.
    [compressor_with_pcb.kicad_pcb]
2026-10-01 Clear DRC on the main board
    - Reference designators sit inside their own outlines, or beside the small
    parts, so none overlap a neighbour or a pad
    - Edge finger pads open the mask on their own side only
    - A board rule allows the TO-92 footprint's own 0.22 mm pad gap, which the
    Power and Ground classes would otherwise flag
    - J1 pin labels move to the fab layer, they ran under parts by the fingers
    - Board name and revision on the silkscreen
    DRC: 0 errors, 0 unconnected, schematic parity clean. Two warnings remain,
    the template's missing Cards library and one K mark touching R41's outline.
    [compressor_with_pcb.kicad_pcb]
2026-10-01 Draw the front board schematic
    The pots, switches and both meters, copied from the main schematic with
    their values and footprints. J1 matches J2 on the main board pin for pin and
    every net keeps the main board's name. Mini toggle footprints added as a
    project library, since the stock library has none.
    ERC: 0 errors.
    [compressor_front.kicad_sch]
2026-10-01 Lay out and route the front board
    35 x 110 mm behind the faceplate, with the panel and its holes drawn on
    User.Drawings and the grid origin on the panel's top-left corner. Controls sit
    on their panel positions, the LM3914/LM3915 either side of the meters, and the
    ribbon header down the back of the right-hand edge.
    DRC: 0 errors, 0 unconnected, schematic parity clean. Two silkscreen
    warnings where outlines are clipped at a pad.
    [compressor_front.kicad_pcb]
2026-10-01 Take the panel holes from the front board
    The toggle layout is now the default and its positions come from the front
    board: RATIO row toggles moved in to 6.9 and 31.2, ATTACK and RELEASE 1.5 mm
    left to clear the ribbon header, meters 9.9 mm apart for the drivers either
    side. Pot and toggle holes open up to 7.2 and 6.5 mm as the faceplate guide
    suggests. Mockups, drawing and DXF regenerated.
    [faceplate.dxf]
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2026-10-01 Put the op amps in sockets
    U1 to U7 use the DIP-8 socket footprint. The pads are the same, so the
    routing and pour are untouched; only the outlines grow. References moved back
    inside them.
    DRC unchanged: 0 errors, 0 unconnected, parity clean.
    [compressor_with_pcb.kicad_pcb, compressor_with_pcb.kicad_sch]
2026-10-01 Use the Jaycar sub-miniature toggles on the front board
    Footprints for the ST0300 (SPDT) from its datasheet: solder lugs on
    2.54 mm in slotted holes, 8.13 x 5.08 mm body. The ST0310 (DPDT) has no
    published drawing, so its footprint assumes the same pitch with rows
    4.7 mm apart. The board now sits about 8.7 mm behind the panel with the
    switch bodies resting on it. Re-routed.
    DRC: 0 errors, 0 unconnected, schematic parity clean.
    [compressor_front.kicad_pcb, compressor_front.kicad_sch]
2026-10-01 Size the panel's toggle holes for the sub-miniature switches
    5.2 mm for the 10-48 bushing, and a note that its 4.06 mm length needs a
    thinner panel around those holes.
    [faceplate.dxf]
2026-10-01 Add 3D models for the pots and toggles
    KiCad ships no model for the Alps RK09K or the Jaycar sub-miniature
    toggles, so the front board showed bare footprints in 3D and in STEP.
    - Pots: Alps' own RK09K1130 STEP, fetched by tools/get_3d_models.sh rather
    than committed, on a project copy of the stock footprint that places it
    on the shaft centre
    - Toggles: simple solids to the ST0300 datasheet, generated by
    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
    [SW_Toggle_SubMini_DPDT_Jaycar_ST0310.step, SW_Toggle_SubMini_SPDT_Jaycar_ST0300.step, compressor_front.kicad_pcb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]
2026-10-01 Add bracket holes to the main board and document the joint
    Two M3 holes by the front edge, 82 mm apart, for the L-bracket to the
    panel. H2 is plated and routed to CHASSIS so the bracket grounds the panel;
    H1 is unplated. README now covers the ribbon, its length and orientation,
    and how each board fixes to the faceplate.
    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
    [compressor_with_pcb.kicad_pcb]
2026-10-01 Fix the bracket hole spacing in the front board README
    H1 and H2 are 85 mm apart (y = 66 and 151), not 82.
2026-10-01 Split Q2's collector from the VCA tail and update the README (#3)
    * Split Q2's collector from the VCA tail
    A wire at x = 62.23 mm joined Q2's collector (with Q8 and Q9) to the
    tail node (Q3, R14, R15). They are now two nets: Net-(Q2-C) on Q2.1,
    Q8.3 and Q9.3, and Net-(Q3-C) on Q3.1, R14.1 and R15.2. The board has
    the new pad nets but not yet the copper to match.
    * Re-route the tail net around R14, R15 and Q3
    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
    [compressor_with_pcb.kicad_pcb, compressor_with_pcb.kicad_sch]
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2026-10-01 Match the split sheets' chip references to the board (#4)
    Pasting the board schematic into the split sheets renumbered five units:
    the VCA recovery amp was U4B (board U1B), the sidechain TL072 was U10
    (board U4), U4's power unit was U10, U7's power unit was U11, and the
    LM3915 was U12 (board U10). They now carry the board's references, so
    the split sheets and compressor_with_pcb have the same 167 parts and the
    same 119 nets.
    [meters.kicad_sch, power.kicad_sch, sidechain.kicad_sch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]
2026-10-02 Simulate the compressor, fix its values, and fit Altronics parts (#5)
    * Make the schematic simulate in KiCad, and add the simulation results
    Every part on the kicad/ sheets now has a SPICE model (Sim.* fields, models in
    kicad/sim/compressor_models.lib), the connectors are excluded from simulation, and the
    root sheet carries a test bench: the rack's supplies, a balanced source, a load and the
    knob settings as .param lines. The netlist is unchanged.
    tools/add_sim_models.py writes the fields. tools/sim/run_all.py exports the netlist with
    kicad-cli and runs the characterisation in ngspice; kicad/sim/README.md has how to run
    it in KiCad and what it found.
    * Bring the compressor's values in lin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
    [SW_Toggle_Mini_DPDT_Salecom_S1350.step, SW_Toggle_Mini_SPDT_Salecom_S1315.step, UTS Mini Mixing Desk - Compressor.kicad_sch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]
2026-10-03 Two LM3914 meters with ten LEDs each, simulated (#6)
    * Swap the level meter's LM3915 for an LM3914 on outputs 1-7
    Nobody stocks the LM3915, so U10 becomes a second LM3914. The LEDs move
    to outputs 1-7 and outputs 8-10 join the top LED, giving a 17 dB scale
    with no added parts. Front board LVL tracks re-routed; BOM regenerated.
    * Give both meters ten LEDs and simulate them
    Adds D27-D29 (GR outputs 8-10) and D37-D39 (LVL outputs 8-10) on all three
    schematics. The front board's meter columns move to a 3.0 mm pitch with
    LVL output 10 at the top; R90/R92 move to a 7.62 mm footprint and C38
    turns to clear the LEDs; the affected nets were re-routed. R92 becomes 4k7
    so RV8 can set the top LED at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
    [altronics.csv, compressor_front.kicad_pcb, compressor_front.kicad_sch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]
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2026-10-03 Re-route the main board, reverse RATIO, and re-plot the Gerbers for both boards (#7)
    * Re-plot the Gerbers for both boards from the current layout
    The committed main-board Gerbers were plotted on 2026-10-01, before the film-cap
    re-place and re-route, so 119 of their holes no longer match the board. Re-plot
    them from the current board, add the front board's set, and zip each for the fab.
    tools/plot_fab.sh does both boards in one go so the zips can be refreshed after
    every board change. The README gets an Ordering section with the fab settings.
    * Re-route the main board: paired IN/OUT, one-piece ground pour
    IN+/IN- and OUT+/OUT- run as pairs 0.6 mm apart on the top layer, with
    one via each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
    [compressor_front-B_Cu.gbr, compressor_front-B_Mask.gbr, compressor_front-B_Silkscreen.gbr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]
2026-10-03 Add a 3D-printable faceplate (#8)
    panel/print/ holds an OpenSCAD model of the toggle-layout faceplate and its STLs:
    the panel (printed face down), the engraved legend as a second-colour body, and a
    fit-test strip. make_panel.py now also writes print/panel_data.scad, so the printed
    panel takes its holes and legend from the same definition as the drawing and DXF.
    3.2 mm thick with a flat back, so everything behind the panel sits as drawn; 12.5 mm
    wells on the front leave 2.0 mm under each pot nut for the short pot bushings.
    [faceplate-fit-legend.stl, faceplate-fit-test.stl, faceplate-legend.stl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]
2026-10-06 Multicolour 3MFs of the printed faceplate (#9)
    make_3mf.py combines the panel and legend STLs into one object with two parts, panel on filament 1 and legend on filament 2: faceplate-multicolor.3mf in Bambu Studio / OrcaSlicer's layout and faceplate-multicolor-prusaslicer.3mf in PrusaSlicer's, plus the same pair for the fit test. Also fixes a non-manifold seam at the bottom mounting hole's countersink.
    [faceplate-fit-test-multicolor-prusaslicer.3mf, faceplate-fit-test-multicolor.3mf, faceplate-fit-test.stl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]
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2026-10-18 BOM as ordered: Altronics, DigiKey and Jaycar, no element14 (#12)
    The element14 order was replaced by the DigiKey backup (film caps, R61/R62, NE5532s, BC549Cs, zener, 100n, bipolars) and the Jaycar order (resistors, TL072, LM3914s, meter LEDs, C14/C35 as 2.2uF bipolars).
2026-10-21 Add a meter calibration script for RV7 and RV8 (#14)
    tools/calibrate_meters.py sets the level (RV8) and gain-reduction (RV7)
    meter trims through an audio interface, a loopback and a multimeter, and
    can sweep each meter against the simulated scale. Works through a combo
    XLR input, diagnoses a missing loopback tone, and catches an implausible
    output reading. README shows installing numpy and sounddevice in a venv.
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
